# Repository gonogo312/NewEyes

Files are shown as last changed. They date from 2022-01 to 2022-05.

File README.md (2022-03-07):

# NewEyes - Умни очила за незрящи хора

# Автор

Иван Цветков - разработил проекта <br />
&emsp;• Username: gonogo, E-mail: i.tsvetkovbg@gmail.com

# Примери

## Screenshots

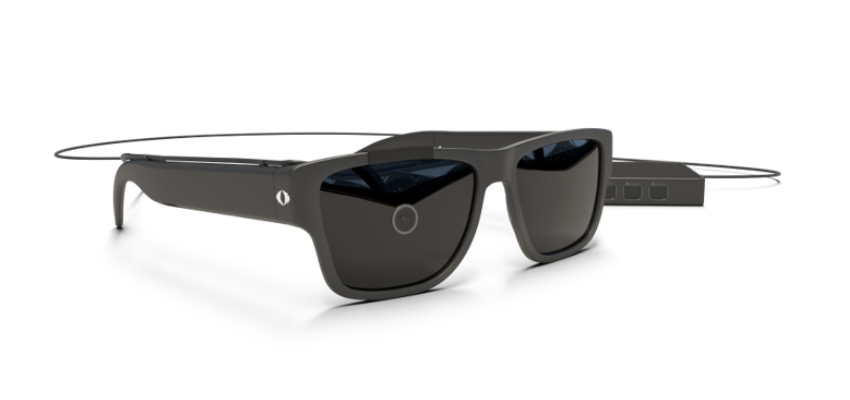
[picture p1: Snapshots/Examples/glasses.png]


<p float="left">
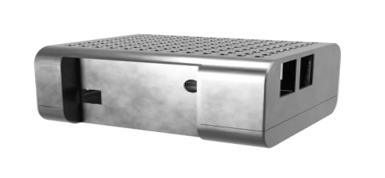
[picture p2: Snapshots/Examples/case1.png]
  
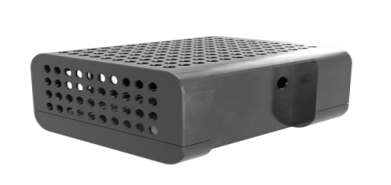
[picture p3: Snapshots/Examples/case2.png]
   
</p>

## Готов продукт

<p float="left">
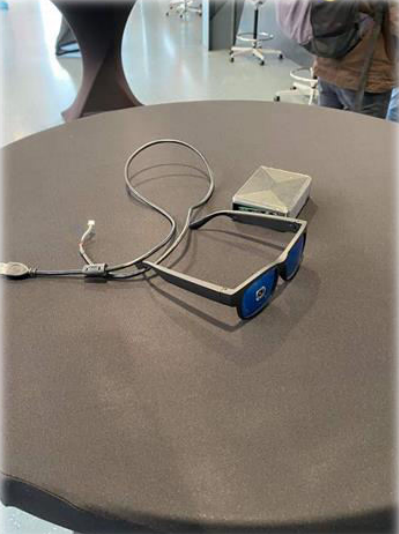
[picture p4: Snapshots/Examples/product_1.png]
  
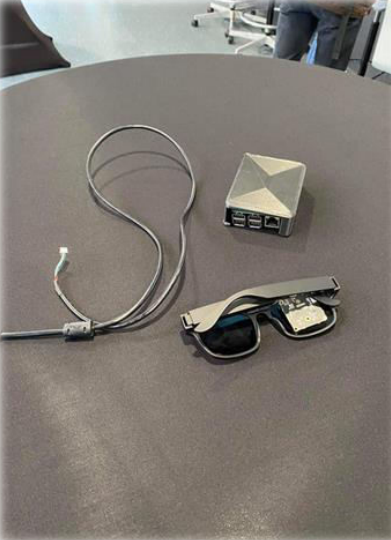
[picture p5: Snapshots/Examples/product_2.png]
   
</p>

## Четене на текст от Български и Английски език <br/>
(Допълнение: Ориентацията на снимките не е от значение, софтуера 
засича неправилната ориентация и изправя или обръща снимката)

<br/><br/>

## Четене на печатен текст  
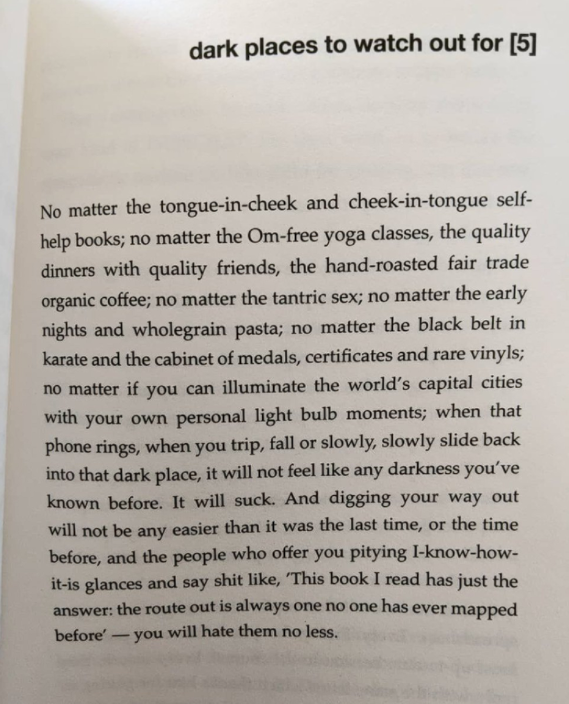
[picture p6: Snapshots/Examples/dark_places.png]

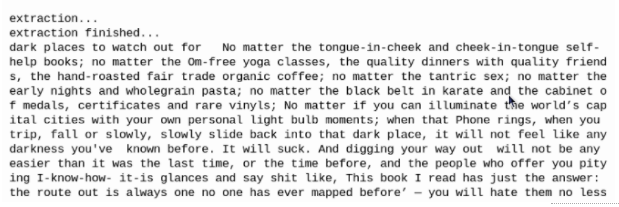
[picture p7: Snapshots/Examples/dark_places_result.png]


<br/><br/>

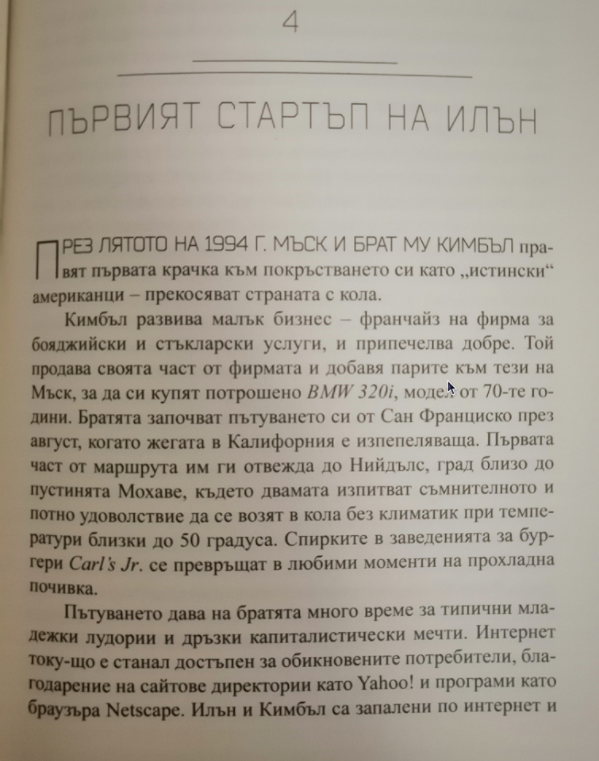
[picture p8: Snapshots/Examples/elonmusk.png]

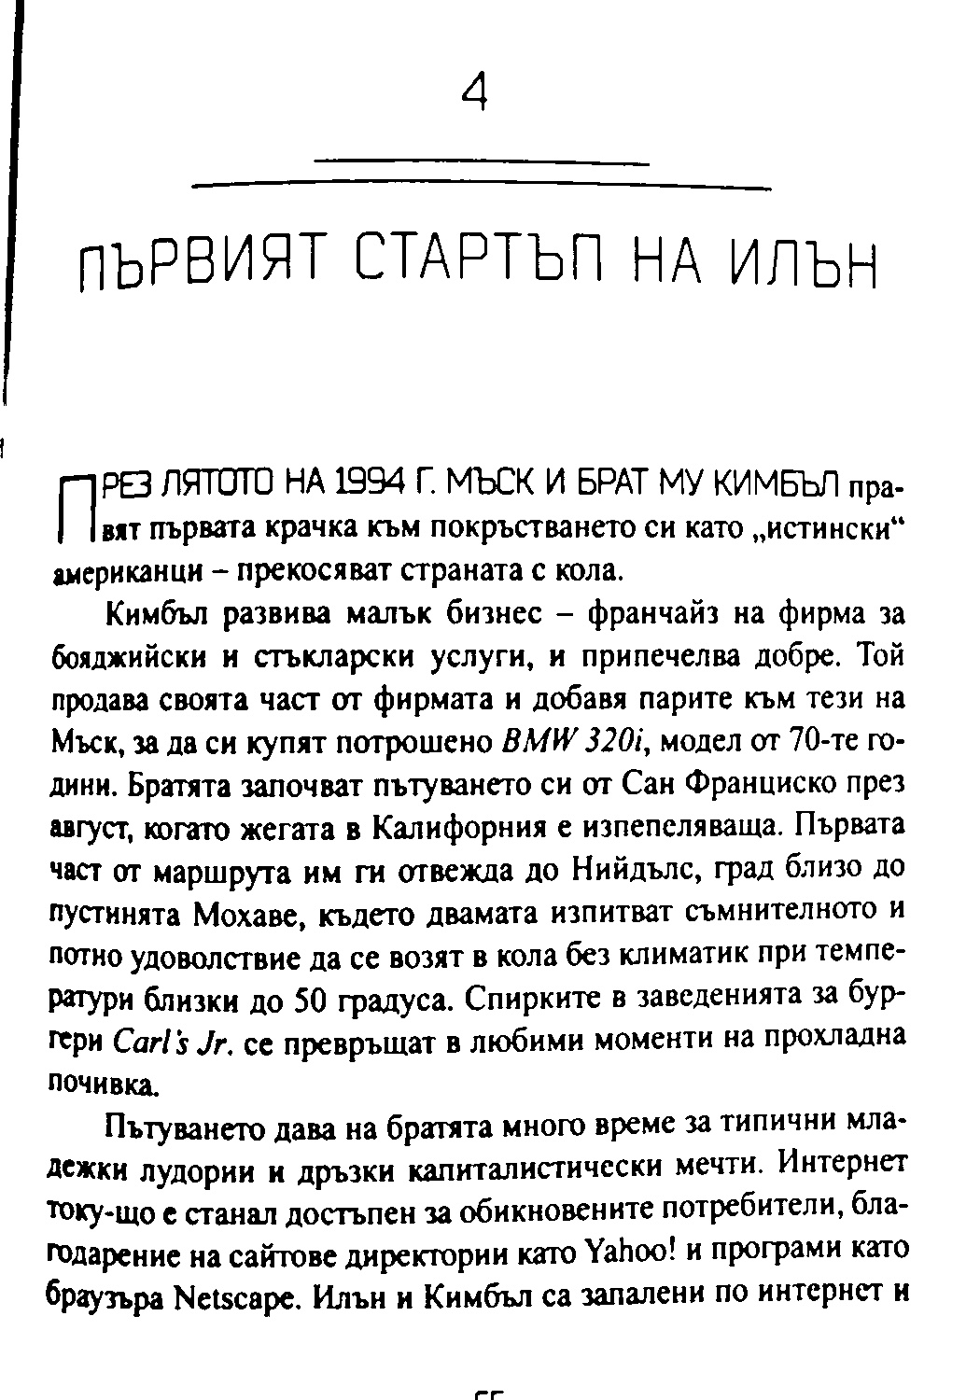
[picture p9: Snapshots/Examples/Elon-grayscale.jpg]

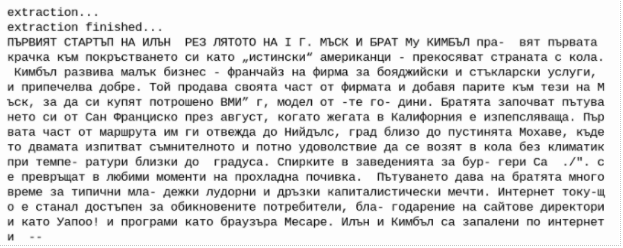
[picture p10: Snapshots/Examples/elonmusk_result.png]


<br/><br/>

## Пример за справяне с неправилната ориентация на текста

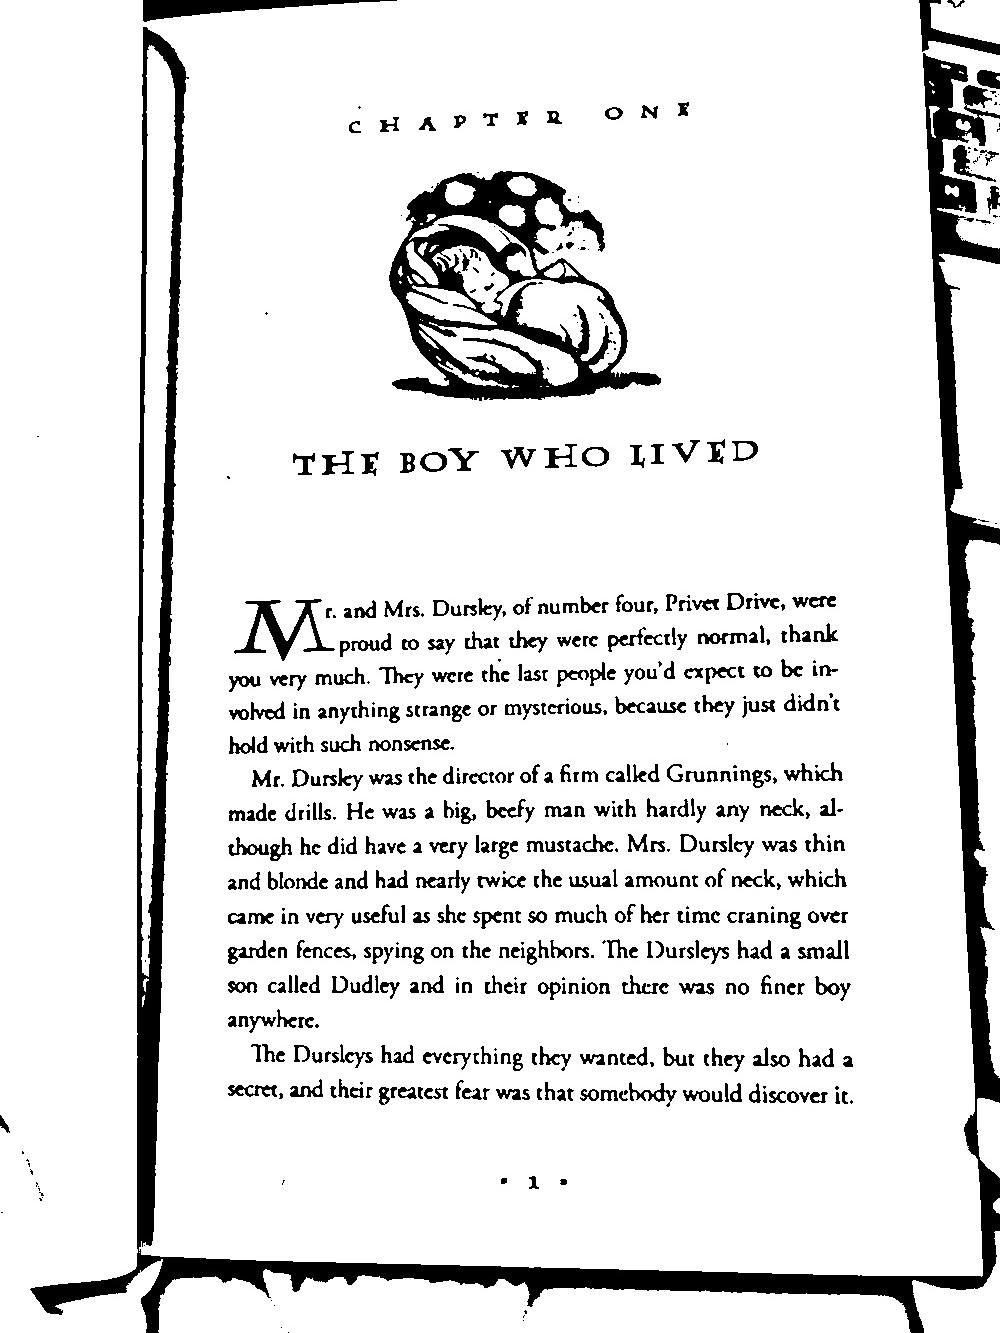
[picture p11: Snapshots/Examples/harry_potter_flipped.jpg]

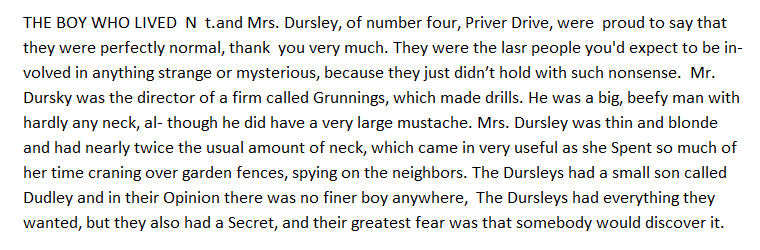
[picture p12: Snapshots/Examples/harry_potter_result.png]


<br/><br/>

## Четене на текст в необичайна среда
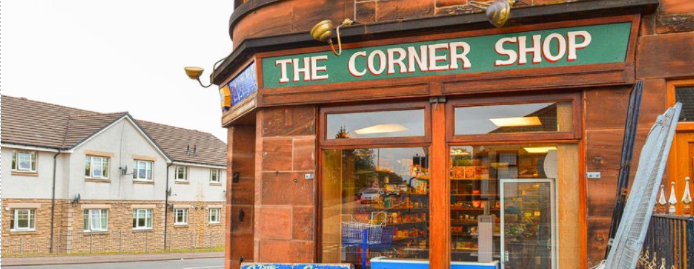
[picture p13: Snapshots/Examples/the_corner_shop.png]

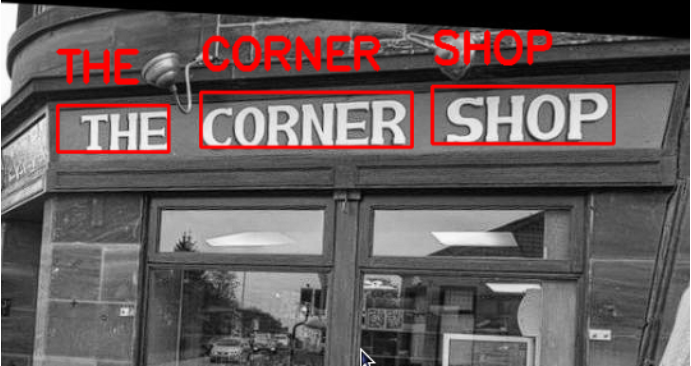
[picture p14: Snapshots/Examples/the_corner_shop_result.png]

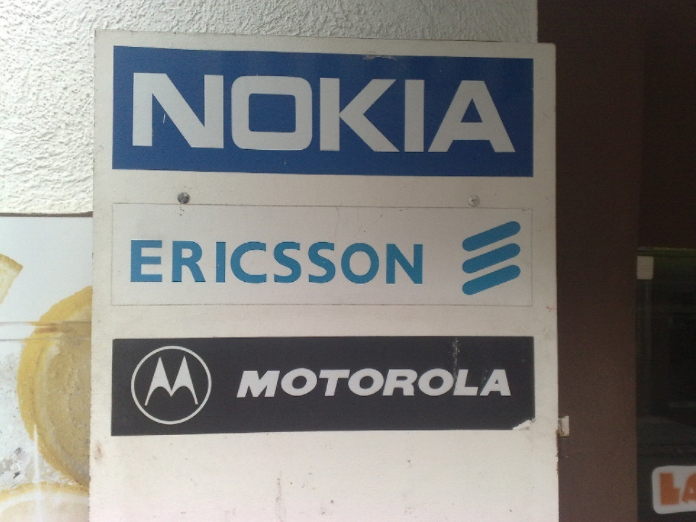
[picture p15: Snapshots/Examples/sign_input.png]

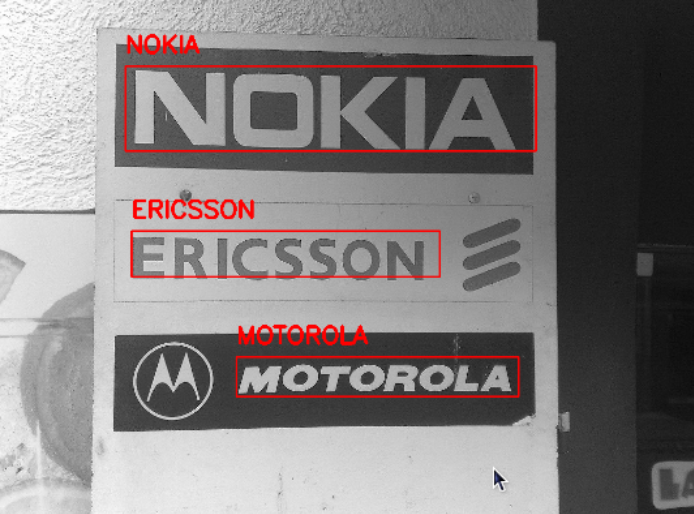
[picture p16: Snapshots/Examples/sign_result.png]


<br/><br/>

## Сканиране на касови бележки
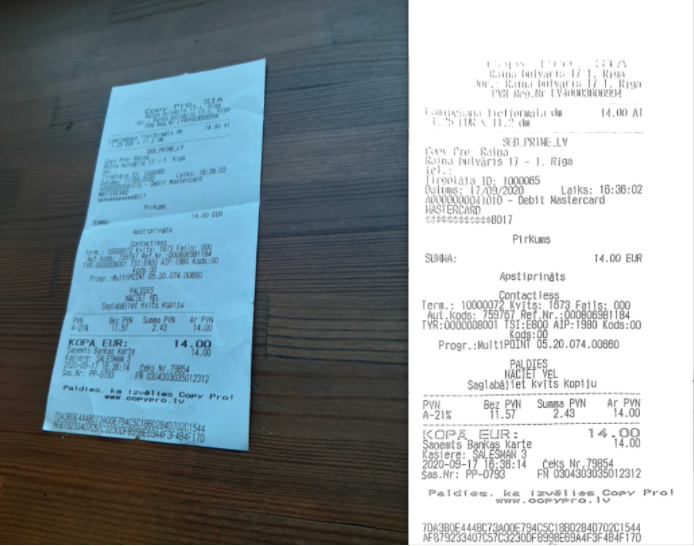
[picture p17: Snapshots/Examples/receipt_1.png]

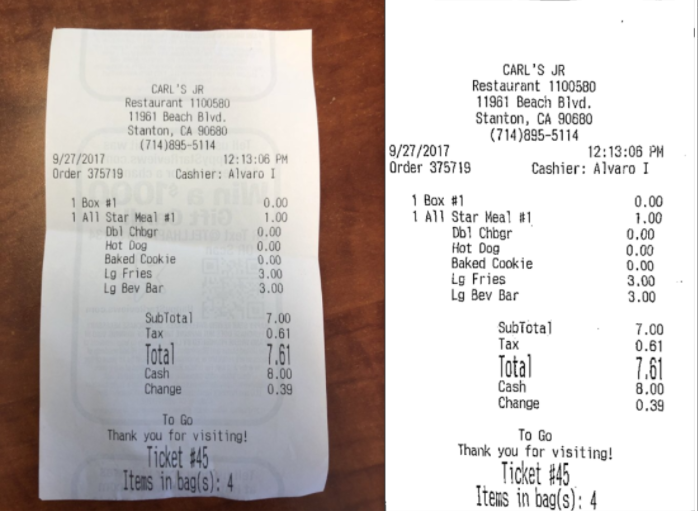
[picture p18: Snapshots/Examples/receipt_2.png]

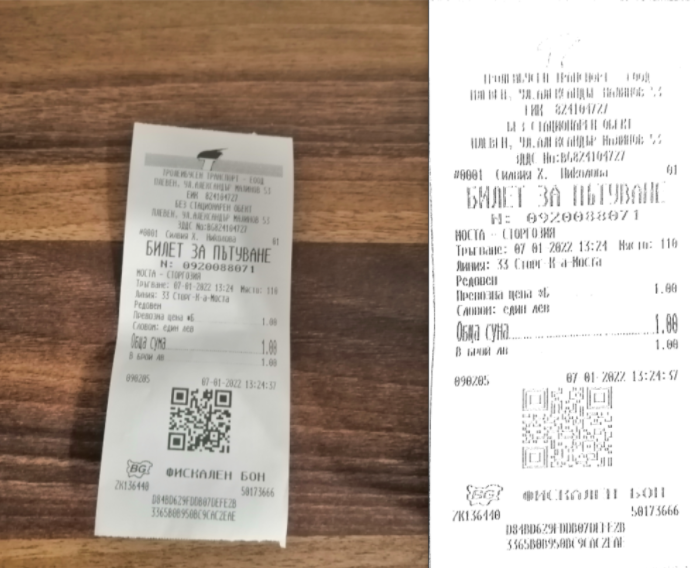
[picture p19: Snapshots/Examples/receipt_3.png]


<br/><br/><br/><br/><br/><br/>

## Разпознаване на обекти и тяхната позиция в пространството
Съответно, след цялостната обработка, разпознаването на обектите и превода на български език,
през говорителите на устройството или през свързаните към устройството слушалки, 
съответното съобщение се изговаря през говорителите или през слушалките в ухото на незрящия човек.

<br/>

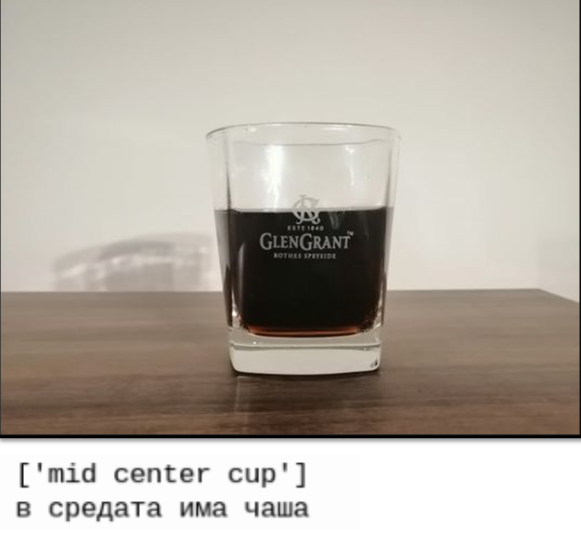
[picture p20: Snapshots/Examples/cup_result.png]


<br/>

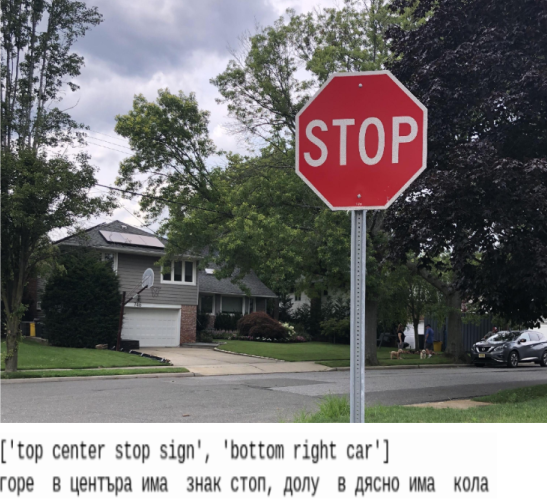
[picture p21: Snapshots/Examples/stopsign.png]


<br/><br/><br/><br/><br/><br/>

## Интерактивна помощ от друг човек чрез камерата на очилата 

Опцията представлява видеочат, чрез който незрящият бива  
навигиран от друг човек (познат/приятел/роднина), като връзката
се осъществява посредством платформата за видео чат Duo 

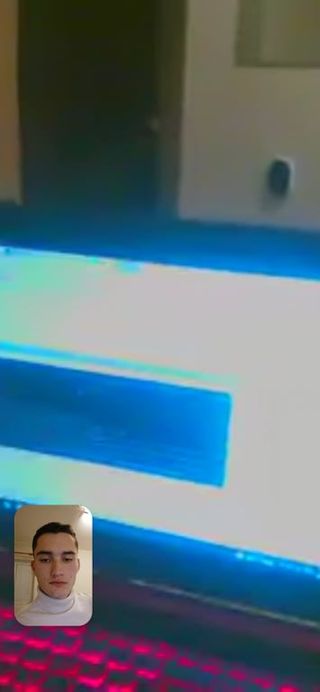
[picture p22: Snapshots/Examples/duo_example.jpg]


<br/><br/><br/><br/><br/><br/>

## Разпознаване на главен цвят от снимка
https://user-images.githubusercontent.com/97058791/152701536-6b37c342-0eb0-4af8-9801-c10c8d0b1d24.mp4

<br/><br/><br/><br/><br/><br/>

## Разпознаване на баркод и QR код
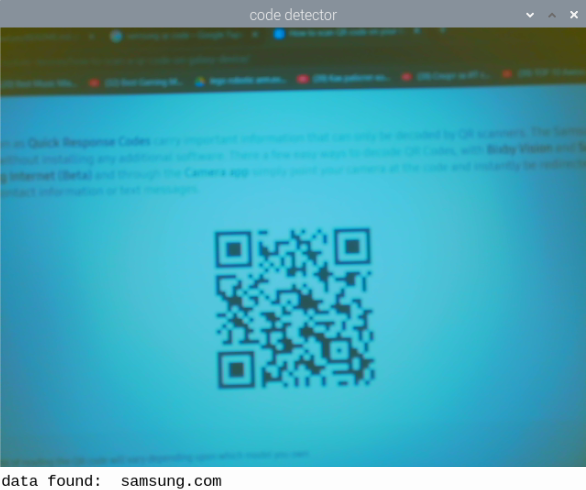
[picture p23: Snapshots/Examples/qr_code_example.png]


<br/><br/><br/><br/><br/><br/>

## Отличия
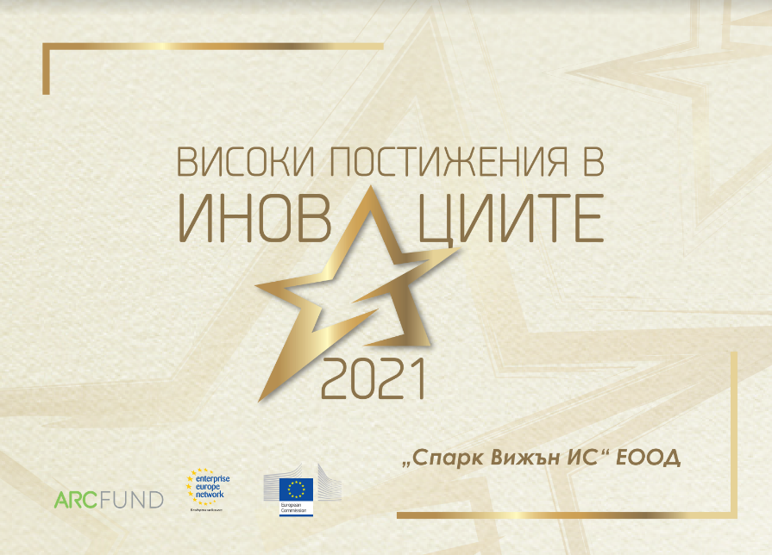
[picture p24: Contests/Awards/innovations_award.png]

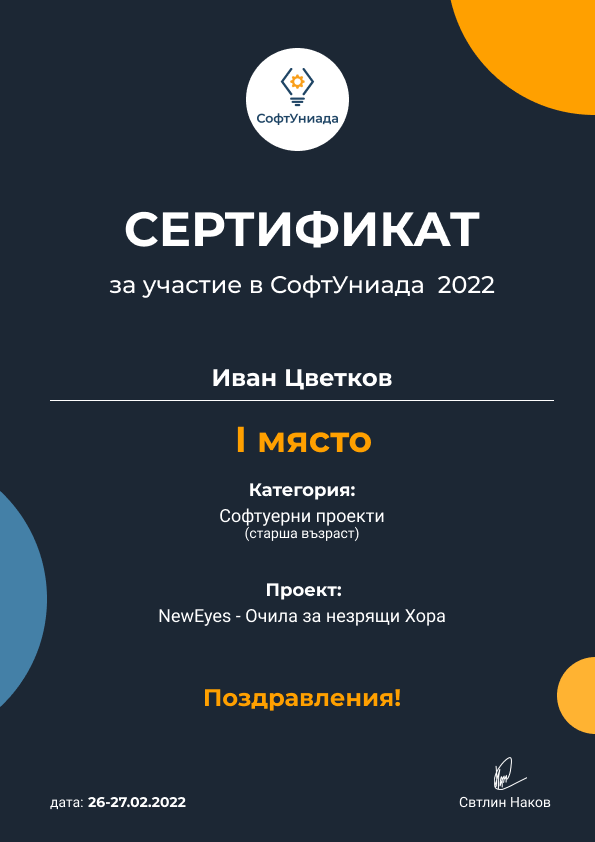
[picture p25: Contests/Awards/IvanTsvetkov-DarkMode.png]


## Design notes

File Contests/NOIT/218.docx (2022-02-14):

NewEyes

Проект №218 Съвременни системи за визуална информация

1. Тема: NewEyes – Очила за незрящи Хора
2. Автор:

Иван Мирославов Цветков

ЕГН: 0346233967

Адрес: Климент Охридски №12, гр. Долни Дъбник

Тел: 0899348344

Имейл: i.tsvetkovbg@gmail.com

МГ “Гео Милев” Плевен, 12 клас

3. Ръководител:

Илко Симеонов

Тел: 088 518 1556

Имейл: ilko.simeonov2000@gmail.com

Позиция: Програмист

Проект № 218, Съвременни системи за визуална информация

4. Резюме

4.1. Цели:

Целта на проекта е да подобри живота на незрящите / хората с тежко увредено зрение, като бъде неизменен помощник в тяхното ежедневие. В зависимост от това от което се нуждае незрящия в дадена ситуация, са предвидени различни по вид и функция функционалности (модове). Всяка функционалност изпълнява строго дефинирана функция, като това помага за лесната използваемост на устройството.

Наличните функционалности, които ще се поддържат от устройството са:

Избираеми функции:

- Четене на книжен/печатен текст
- Четене на текст в необичайна среда
- Единично разпознаване на обекти
- Разпознаване на обекти в реално време
- Позвъняване на познат при нужда от помощ
- Разпознаване на QR & Barcode кодове
- Сканиране на касови бележки
- Разпознаване на валута / банкноти
- Разпознаване на главен цвят в снимка
- Разпознаване на лица и емоции

Автоматични функции работещи винаги след стартирането на устройството:

- Разпознаване на жестове с ръце
- Умен гласов асистент

Програмният код е лицензиран под GNU General Public License v3.0

За разработката на проекта се използва Github, което представлява децентрализирана система за контрол на версиите на файлове. Програмният код и примери от главните функционалности на проекта са достъпни на следния адрес:

https://github.com/gonogo312/NewEyes

Проект № 218, Съвременни системи за визуална информация

4.2. Основни етапи в реализацията на проекта:

- Създаване на идеята
- Избиране на подходящи технологии
- Обмисляне на архитектурата и взаимодействието между различните модули
- Детайлно проучване нуждите на клиента
- План за реализация на проекта
- Разработка на устройството (хардуер/софтуер)
- Тестване на главните функционалности чрез помощта на незрящи доброволци
- Обработка на допълнителни клиентски изисквания / предложения
- Изкарване в продъкшън среда (готов за използване продукт)
- Бъдещи планове

4.3. Ниво на сложност на проекта:

В проекта са използвани множество модерни технологии и различни модули хардуер. Използваните технологии и библиотеки са проучени и тествани в реална среда, така че да изпълняват различните по вид функционалности на устройството по най-оптималният начин. Поради гореспоменатите причини определям „NewEyes“ като проект от високо ниво на сложност.

4.4. Логическо и функционално описание на решението:

4.4.1. Генерална архитектура

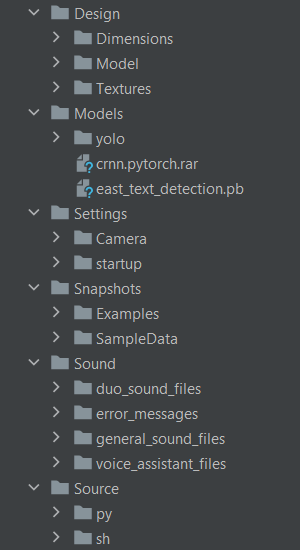
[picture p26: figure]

Проект № 218, Съвременни системи за визуална информация

- Design
  - Model

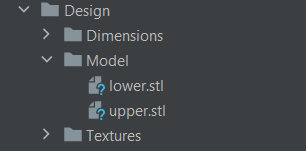
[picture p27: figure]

Upper.stl и съответно Lower.stl представляват двете части на модела от които е изградена кутията на устройството.

  - Dimensions

Съдържа схемите по които е изграден модела на кутията, съответно размерите на всеки елемент от хардуера в нея – едноплатков компютър Raspberry Pi 4, литиева батерия PiSugar2 Pro, SIM карта и други.

Проект № 218, Съвременни системи за визуална информация

  - Textures

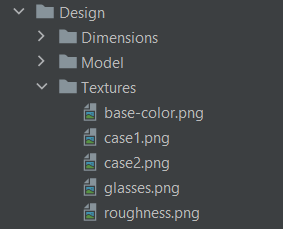
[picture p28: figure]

Съдържа отделните части на модела като изображение, цялостният модел и цветова гама на модела.

- Models

Yolo, CRNN.PythonTorch и east_text_detection моделите дават способността на устройството да разпознава текст и обекти по най-оптималният начин в съотношение с изчислителната мощност на хардуерните компоненти.

  - Yolo

Съвкупност от различни модели, използвани за разпознаване на обекти.

  - CRNN.PythonTorch

Модел и код за трениране на модела. Прилага се при разпознаването на текст в необичайна среда (функционалност №2) – четене на текст от табели, тролейбуси, коли и други идентични източници.

  - East_text_detection.pb

Подобен модел, използван при четенето на текст.

Проект № 218, Съвременни системи за визуална информация

- Source
- Python

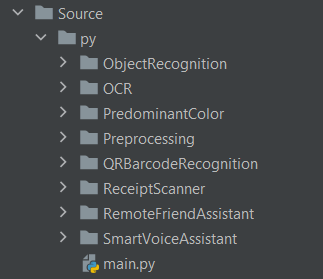
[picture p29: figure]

    - OCR

NewEyes.Source.python.OCR.book_ocr дава функционалността за четене на печатен текст.

NewEyes.Source.python.OCR.crnn_ocr предоставя функционалността за четене на текст в необичайна среда.

    - ObjectRecognition

NewEyes.Source.python.ObjectRecognition.yolo съдържа класовете и методите за разпознаването на обекти, тяхната позиция в пространството и разстоянието до всеки обект.

NewEyes.Source.python.ObjectRecognition.start_obj_recog

предоставя функционалността за разпознаване на обекти от снимка.

NewEyes.Source.python.ObjectRecognition.realtime_yolo_obj_recog предоставя

функционалността за разпознаване на обекти в реално време.

    - PredominantColor

NewEyes.Source.python.PredominantColor.predominant_clr дава функционалността за разпознаване на главен цвят от снимка.

Проект № 218, Съвременни системи за визуална информация

    - Preprocessing

NewEyes.Source.python.Preprocessing.image_processing пази методите използвани за обработката на снимките.

    - QRBarcodeRecognition

NewEyes.Source.python.QRBarcodeRecognition.qr_barcode функционалност за разпознаване на QR & Barcode кодове в реално време.

    - ReceiptScanner

NewEyes.Source.python.ReceiptScanner.receipt_scanner съдържа функционалността за сканирането и четенето на касови бележки.

    - RemoteFriendAssistant

NewEyes.Source.python.RemoteFriendAssistant.duo_google пази функционалността за позвъняване на друг човек чрез мобилният му номер и фийд от камерата чрез платформата Duo.

    - SmartVoiceAssistant

NewEyes.Source.python.SmartVoiceAssistant.voice_recog дава функционалността за Speech-to-Text, което се използва при функционалността гласов асистент.

    - HandGestureRecognition

NewEyes.Source.python.HandGestureRecognition дава функционалността за разпознаване на жестове с ръце.

    - Main.py

Съдържа основният код, чрез който потребителят навигира през списъка с функционалностите, изпълнява избрана функционалност. При стартиране се създават нишки (Threads) за функционалностите SmartVoiceAssistant и HandGestureRecognition.

Проект № 218, Съвременни системи за визуална информация

  - Bashsc

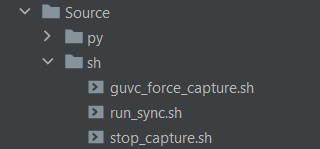
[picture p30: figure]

    - Guvc_force_capture.sh прави снимка чрез камерата на очилата чрез програмата guvcview (софтуер използван за обработката на UVC потоци).
    - Stop_capture.sh изключва guvcview след като се направи и запази снимката.
    - Run_sync спрямо въведена часова зона, синхронизира часовника на устройството чрез NTP (Network Time Protocol).
- Settings
- Camera
  - NewEyes.Settings.Camera.default.gpfl съдържа настройки за конфигуриране на параметри като Focus, Brightness, Contrast, Saturation и други, използвани при правенето на снимка чрез софтуера guvcview.

Проект № 218, Съвременни системи за визуална информация

- Startup/autostart
- NewEyes.Settings.startup.autostart.autorunfile.desktop съдържа инструкции чрез които при включване на устройството се изпълнява основният код, main.py.
- Snapshots

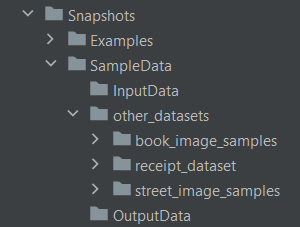
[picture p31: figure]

- Examples

Съдържа примери от главните функционалности и техните резултати.

- SampleData/other_datasets съдържа примери използвани при тестването на функционалностите и dataset използван при тестването на функционалността ReceiptScanner.

Проект № 218, Съвременни системи за визуална информация

- Sound

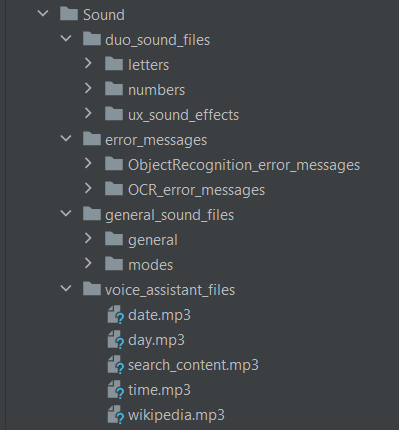
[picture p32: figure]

Съдържа аудио файловете във формат *.mp3 и *.wav използвани при различните функционалности, разделят се в 4 основни категории:

- General_sound_files
- Duo_sound_files
- Error_messages
- Voice_assistant_files

4.4.2. Използвани библиотеки:

- GoogleSpeech – Speech класа позволява създаването на *.mp3 файлове с даден текст.
- GpioZero – Button класа позволява достъпа до бутоните.

Проект № 218, Съвременни системи за визуална информация

- OS & MPG312 – OS библиотеката позволява извикването на MPG312 music player, който прави възможно извикването и изпълняването на аудио файлове.
- Imutils – Предоставя базови функции за обработка на снимки, като някои от тях са non_max_suppression, label_contour, four_point_transform, put_text и други.
- Pytesseract – Енджин, използван при разпознаването на текст от снимка, предоставящ различните модове/опции още наречени Page Segmentation Modes и OCR Engine Mode или PSM и OEM. Някои от използваните модове в проекта са:

PSM

1. Automatic page segmentation with OSD.
2. Fully automatic page segmentation (No OSD)

OEM

1. Neural nets LSTM engine only.
2. Legacy + LSTM engines.
3. Default
- Subprocess – Библиотека предоставяща функционалността за създаване на нови процеси използвани за изпълняването на функциите на устройството изпълняващи се в реално време.
- Threading – Класът Thread дава възможност за създаването на нови нишки използвани за изпълнението на функционалности като SmartVoiceAssistant, HandGestureRecognition.
- Pyzbar – Декодира засеченият QR или Баркод.
- TextBlob – TextBlob API позволява поправка на грешно прочетен текст чрез NLP (Natural Language Processing), който дава възможността детайлен анализ на върнатият текст. Някои от възможностите на библиотеката са: Sentiment analysis, Classification, Parsing, Spelling correction и други.

Проект № 218, Съвременни системи за визуална информация

- OpenCV – Предоставя множество фундаментални функции използвани при обработката на снимки и заснемане в реално време.
- MySql.Connector – Предоставя достъп до локалната MySQL база данни, което позволява изпълняването на заявки за четене и промяна на данни.
- SpeechRecognition – Дава възможността за Speech-to-Text.
- Други библиотеки – Numpy, argparse, random, time, datetime, sys, io, signal, pyttsx3, pygame, skigame, pynput, webbrowser, pyautogui, wikipedia, re.

Структура на MySQL базата данни:

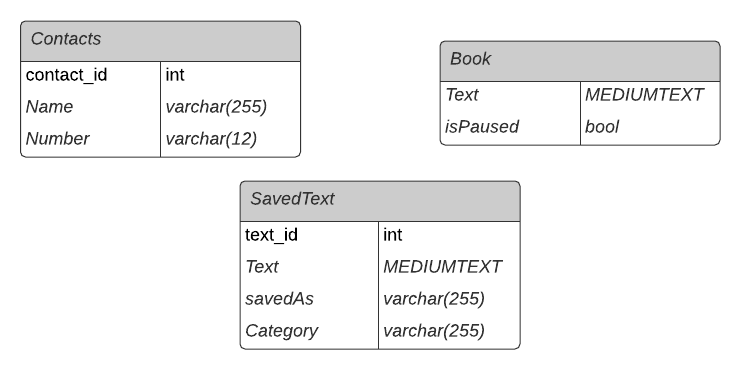
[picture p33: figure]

Проект № 218, Съвременни системи за визуална информация

4.4.3. Хардуерна архитектура и компоненти

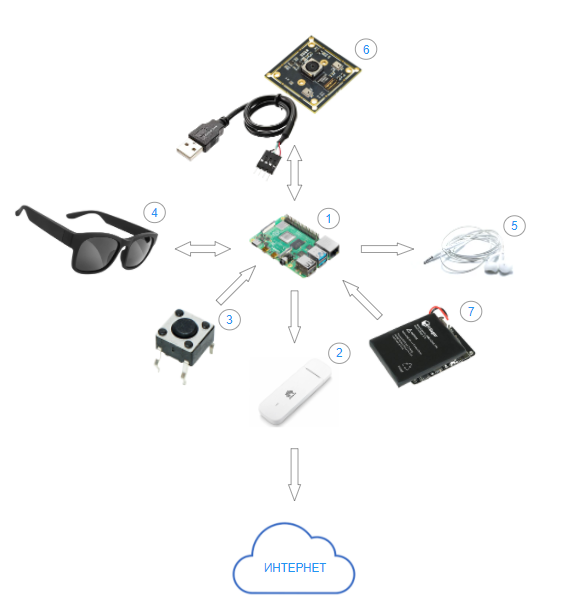
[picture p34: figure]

1. Компютър Raspberry Pi 4 Model B

2. Huawei 4G Dongle

3. 3x Бутона

4. Bluetooth очила с вградени говорители

5. Слушалки (по избор)

6. Arducam 4K 16MP камера

7. Pisugar2 | Литиева Батерия | 5000mAh

Проект № 218, Съвременни системи за визуална информация

4.4.4. Дизайн на системата


Проект № 218, Съвременни системи за визуална информация

4.4.5. Външен вид на готовият продукт

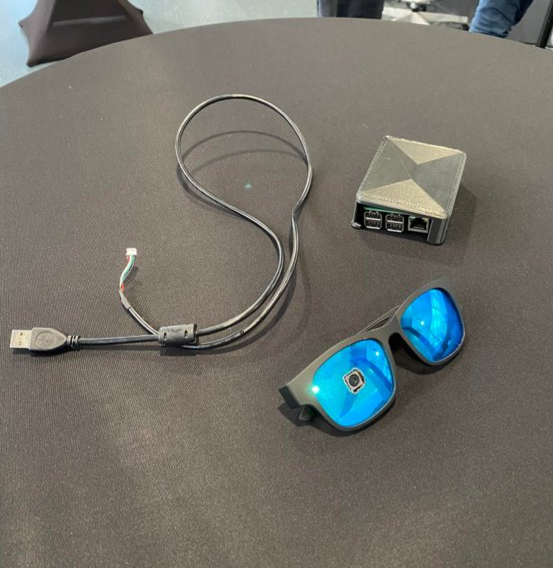
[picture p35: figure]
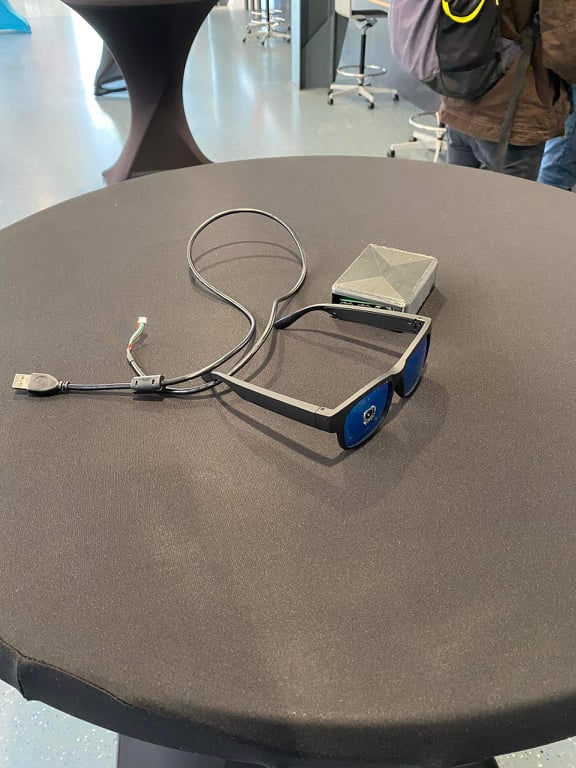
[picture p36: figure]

4.5. Реализация:

4.5.1. Избор на технологии

За разработката на проекта са проучени в детайли и избрани набор от модерни технологии и инструменти.

Технологиите включват програмен език Python, MySQL база данни, Pytesseract енджин за извличане на текст от снимка, OpenCV обработка на снимки и други.

Проект № 218, Съвременни системи за визуална информация

4.5.2. Описание на софтуерните решения

При разработката на различните функционалности са използвани различен набор от стъпки и инструменти при обработката за постигане на оптимални резултати. Използвани алгоритми и техники при разработването на модовете са следните:

1. Алгоритъм при обработката на снимки съдържащи печатен текст
- Grayscale

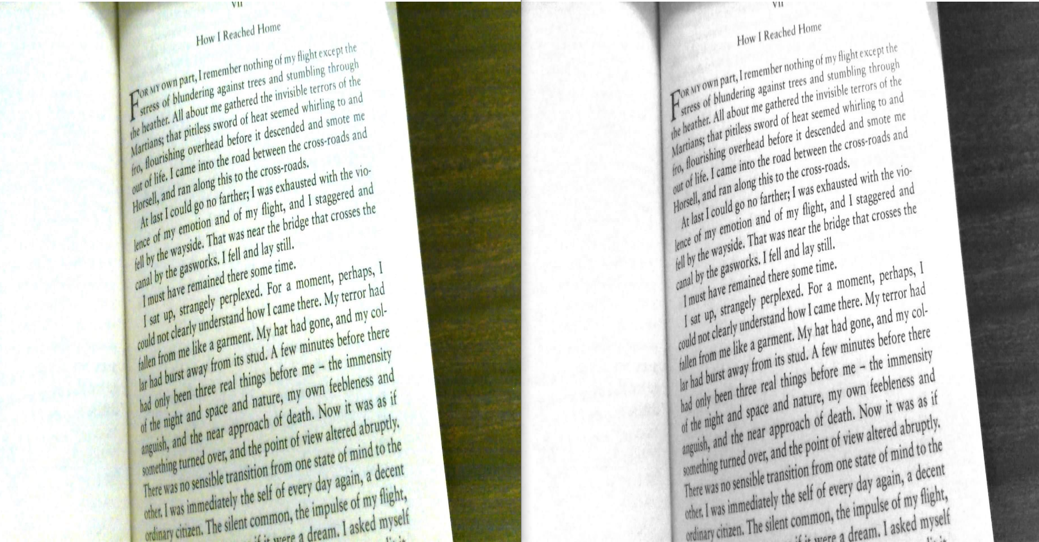
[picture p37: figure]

Проект № 218, Съвременни системи за визуална информация

- Deskew - Изправяне на снимката спрямо ориентацията на текста.

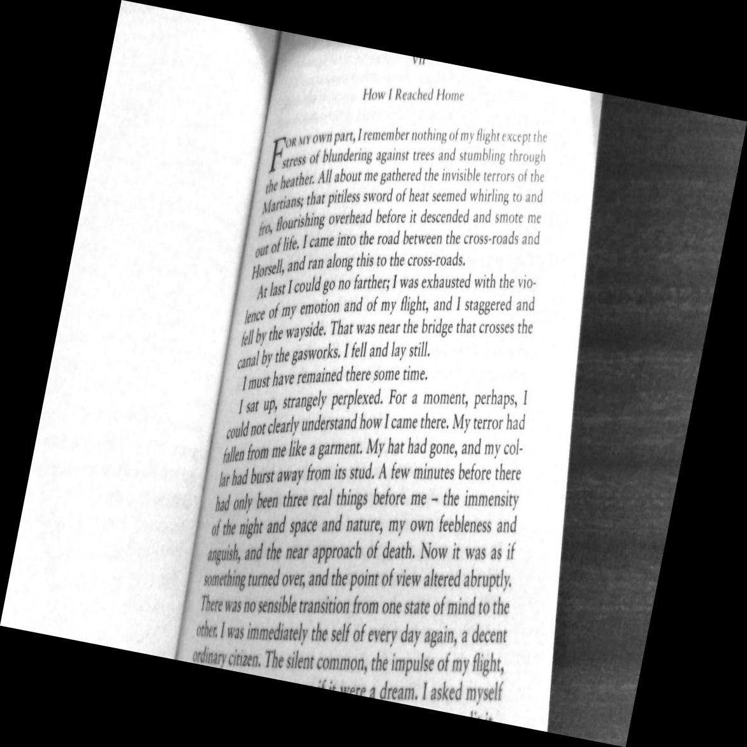
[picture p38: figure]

- OSD - Проверка на ориентацията, идентифициране на езика, при допусната грешка в ориентацията на текста, снимката се преработва отново.
- Dilation - Морфологична операция, увеличаваща белият регион от снимката.
- Noise Reduction - Намаляване на шума от снимката, чрез използването на median blur.
- Adaptive Thresholding - Поради способността да задава автоматично thresholding стойности за всеки пиксел се намалява загубата на информация от снимката до минимум.

Проект № 218, Съвременни системи за визуална информация

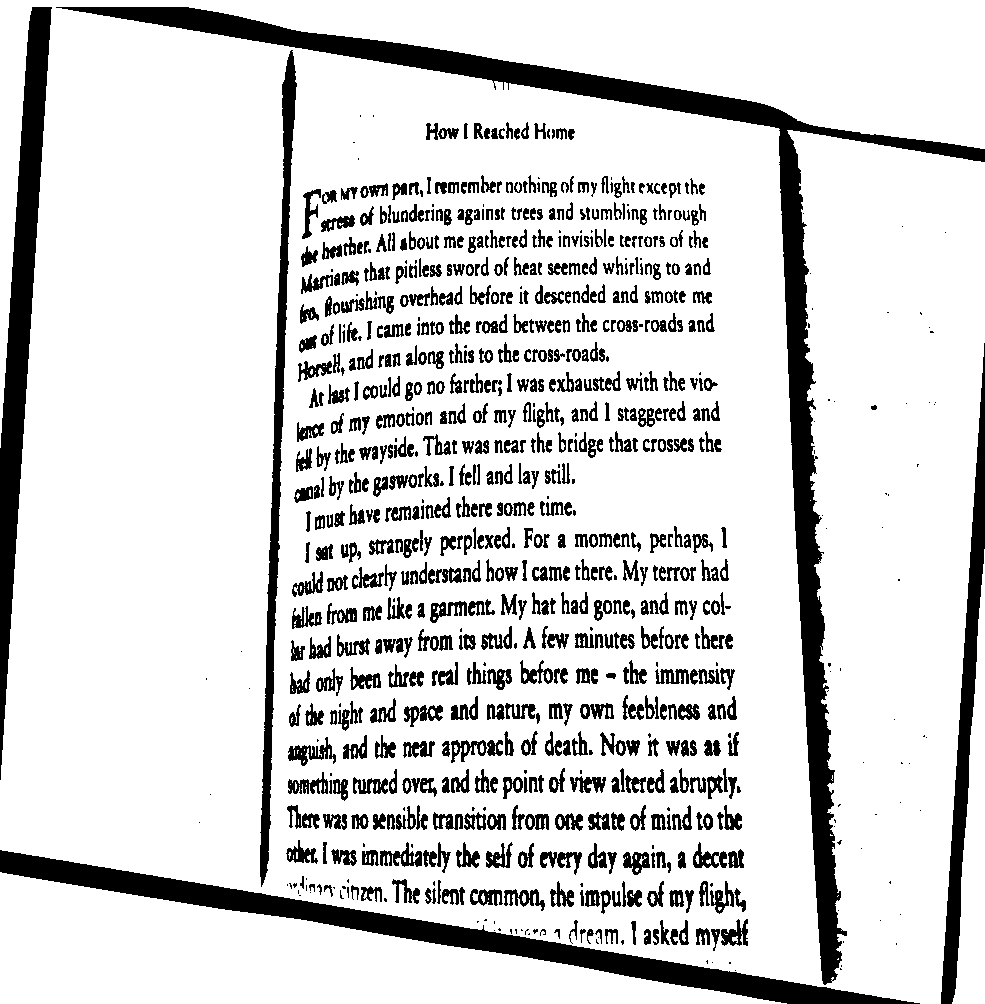
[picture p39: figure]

- Извличане на текста с Pytesseract

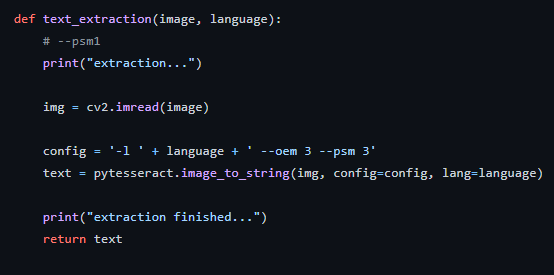
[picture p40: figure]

Проект № 218, Съвременни системи за визуална информация

Резултат:

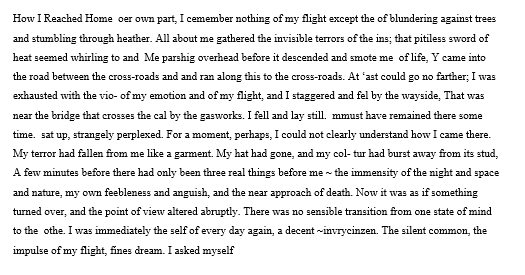
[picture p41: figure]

2. Алгоритъм при обработката на снимки съдържащи текст в необичайна среда

За обработката на снимки в необичайна среда се използва невронна мрежа тип FCN – Fully Convolutional Network.

- При обработката, на снимката се засичат Bounding Boxes на отдените парчета текст чрез FCN моделът на невронната мрежа.
- След засичането на всички налични Bounding Boxes, Non-Maximum Suppression техниката премахва онези Bounding Boxes, които са с коефициент на точност – confidence, по-нисък от зададеният. В нашият случай, коефициентът на точност е 0.6, при което се елиминират повечето засечени Bounding Boxes на обектите.

Проект № 218, Съвременни системи за визуална информация

- След филтрацията на кутиите чрез Non-Maximum Suppression, чрез IoU – Intersection Over Union техниката, намираме сечението на останалите Bounding Boxes.
- Извличаме текста от всяка резултантна кутия чрез Pytesseract.

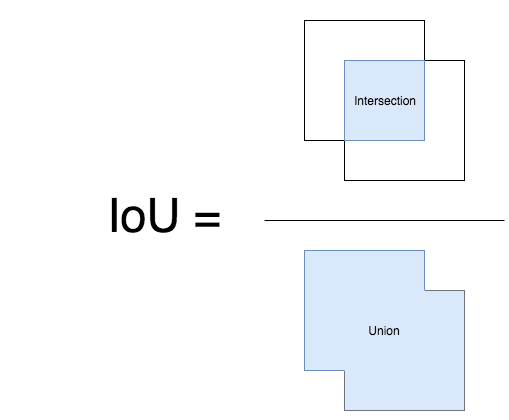
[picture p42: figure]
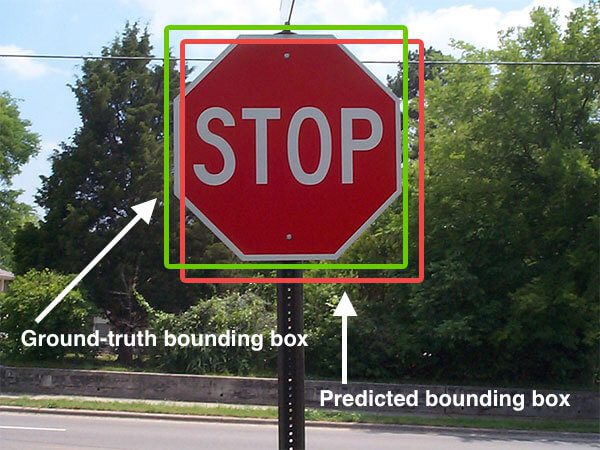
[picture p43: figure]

Проект № 218, Съвременни системи за визуална информация

3. Алгоритъм при обработката на снимки съдържащи обекти

При обработката се използва система за засичане на обекти наречена YOLO – You Look Only Once. Използваната невронна мрежа от YOLO е от тип CNN – Convolutional Neural Network. Предимството на YOLO е в бързината и точността, като за разлика от други невронни мрежи като R-CNN – Region-based Convolutional Neural Network и FAST R-CNN, които се нуждаят от множество повторения на стъпките, YOLO извършва всички стъпки само веднъж. Стъпките през които YOLO минава за разпознаване на обектите от дадена снимка са следните:

Термини:

Classification – Спрямо вида на обекта се задава клас, който отговаря на характеристиките на дадения клас.

Localization – Намиране на местоположението на обект и създаване на Bounding Box около него.

- Локализация на обектите и задаване на Bounding Boxes около обектите, коефициент на точност и класификация за всеки обект.
- Използване на техниката Non-Maximum Suppression.
- Използване на техниката Intersection over Union.
- Извличане на данните за обектите от всяка резултантна кутия.
4. Алгоритъм при сканирането на касови бележки
- Edge Detection - Намиране на върховете на касовият бон.

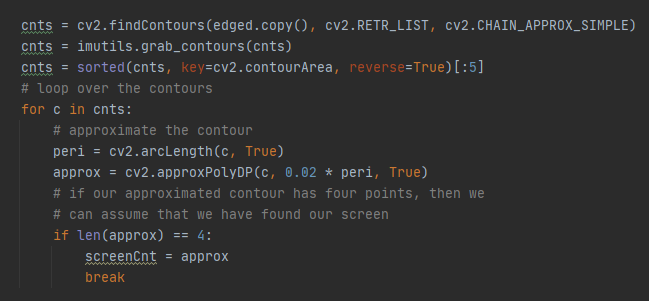
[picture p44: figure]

Проект № 218, Съвременни системи за визуална информация

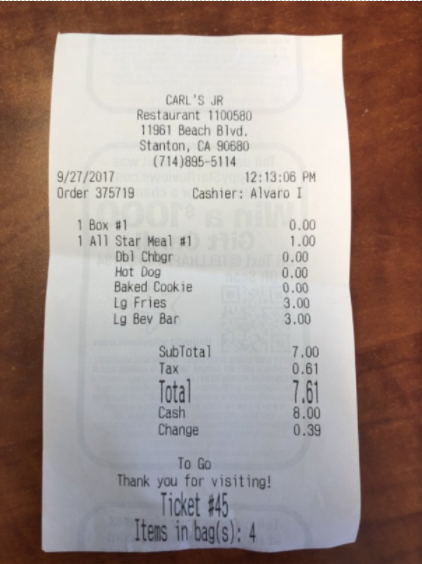
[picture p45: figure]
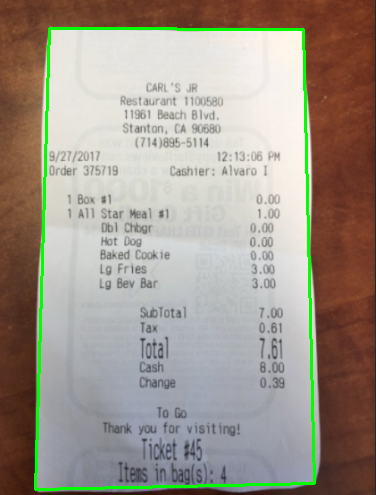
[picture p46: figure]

- Преобразуване на засечения регион в 2D картина, чрез което енджинът за извличане на текст се справя оптимално при извличането на текст от касови бележки.

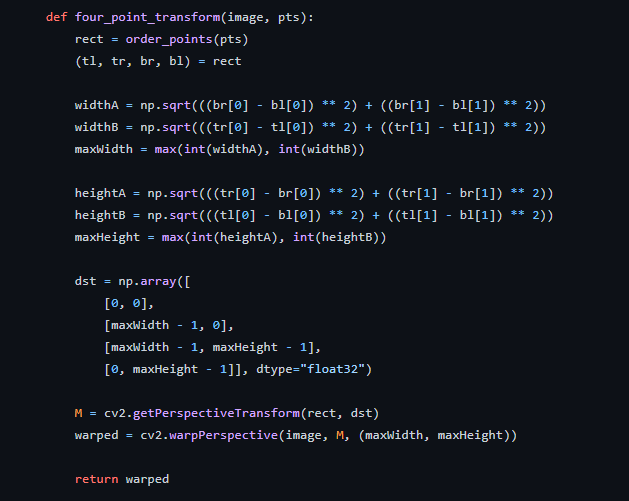
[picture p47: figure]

Проект № 218, Съвременни системи за визуална информация

Резултат от обработката:

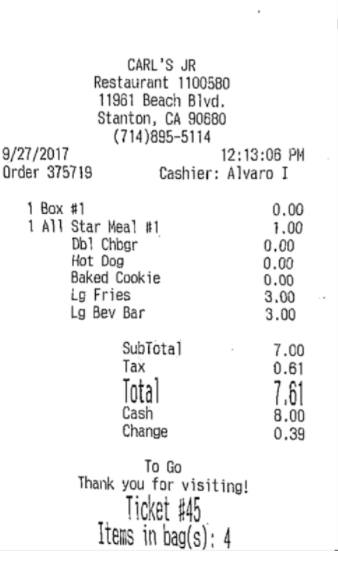
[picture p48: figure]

За обработката на снимки при разпознаването на валута / банкноти и тяхната стойност се обработват данните по идентичен начин както при сканирането на касови бележки.

Проект № 218, Съвременни системи за визуална информация

4.6. Описание на приложението:

Менюто на устройството е проектирано по лесен за навигиране и използване начин от страна на потребителя. Преди използване се поставят очилата, като устройството седи в джоба/ръката на незрящия човек. 3D структурата и тежестта на устройството го прави удобно при използване за дълъг период от време.

- Устройството се стартира чрез Switch от дясната страна на кутията.
- Избираеми опции и активация: При натискането на бутона за активиране на избрана функционалност, компютъра подава сигнал към камерата и прави снимка или съответно пуска Realtime Video Stream от който да вземе всеки фрейм по отделно. Като след обработката, от говорителите на очилата се изговаря съответното съобщение.
- Функции работещи в реално време: По всяко време след стартирането, независимо от избраната чрез бутоните опция, гласовият асистент изчаква команда за активация. При изричането на дефинираната команда, гласовият асистент позволява притока на входни данни. Пример за това са известните гласови асистенти като Siri, Alexa и други. Някои от функциите на гласовият асистент са активиране на функционалност, търсене в интернет, пускане на музика, спиране и пускане на звуков файл, запазване в базата данни прочетен текст от книга. Разпознаването на жестове с ръце позволява функции като спиране, пускане на звуков файл, намаляване на звука от говорителите и други.

Практически примери на някои от функционалностите (стар модел на очилата с работещи главни функционалности за четене на текст и разпознаване на обекти) и интервю с Инж. Павлин Ангелов, член на Управителният Съвет на Съюзът на Слепите Хора в България са достъпни на следния адрес:

https://sparkvision.tech

Проект № 218, Съвременни системи за визуална информация

4.7. Заключение:

NewEyes е устройство, което дава на незрящите хора онази самостоятелност и независимост, която не са имали преди. Проектът има за цел да подобри живота на незрящите хора, като бъде неизменен помощник в тяхното ежедневие. Уникалното на NewEyes е това, че е един от първите по рода си проект, които улесняват живота на незрящите хора и хората с тежко увредено зрение, като им помагат с ежедневни дейности. Основните проблеми на проекта бяха успешно разрешени. За в бъдеще се очаква разрастване, подобряване и добавяне на нови функционалности, като голяма част от тях идват от обратната връзка и контакта с незрящите хора от Съюза на Слепите Хора в България използващи устройството ежедневно.

Основните предимства на NewEyes са бързодействието и точността, затова ще се обърне внимание на следните характеристики на устройството:

- Хардуерна оптимизация
- Бързодействие при изпълнение
- Точност при изпълнение
- Подобряване на наличните функционалности
- Добавяне на нови функционалности
- Дистанционни софтуерни ъпдейти
- Други

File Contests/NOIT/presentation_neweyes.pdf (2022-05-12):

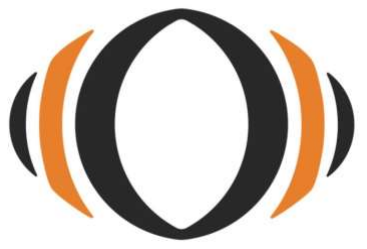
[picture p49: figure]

# NewEyes

## КАКВО ПРЕДСТАВЛЯВА ПРОЕКТЪТ?


NewEyes представляват очила, които подобряват живота на слепите хора и хората с тежко
увредено | зрение, | като | им
помагат с ежедневни дейности.

## ФУНКЦИОНАЛНОСТИ

✓ Четене на текст от различни източници на български и английски език
- Четене на печатен текст
- Четене на текст в необичайна среда

✓ Разпознаване на обекти
- Разпознаване на обекти от снимка
- Разпознаване на обекти в реално време

✓ Позвъняване на познат при нужда от помощ ✓ Разпознаване на баркод и QR код
✓ Сканиране и прочит на касови бележки
✓ Разпознаване на валута и стойност
✓ Разпознаване на цвят
✓ Разпознаване на жестове с ръце
✓ Гласов асистент


## КАК РАБОТИ?

## ПРИМЕРИ


## УСЪВЪРШЕНСТВАНЕ И БЪДЕЩИ ПОДОБРЕНИЯ


### - Хардуерна оптимизация

### - Софтуерна оптимизация

### - Бързодействие и точност при изпълнение

### - Подобряване на наличните функционалности

### - Добавяне на нови функционалности

### - Други


## ХАРДУЕРНА АРХИТЕКТУРА


1. Компютър Raspberry Pi 4 Model B
2. Huawei 4G Dongle
3. Бутони
4. Bluetooth очила с вградени говорители
5. Слушалки (по избор)
6. Arducam 4K 16MP камера
7. Pisugar2 | Литиева Батерия | 5000mAh

## ВЗАИМОДЕЙСТВИЕ


Взаимодействието между хардуера
и | софтуера | се | извършва | от
специален едноплатков компютър Raspberry Pi 4.


## С КАКВО Е УНИКАЛЕН ПРОЕКТЪТ?


- Висококачествен продукт;
- Бързодействие и точност;
- Голям брой поддържани функционалности;
- Най–ниска цена на световния пазар;
- Един от първите по рода си проект;
- Полезен за обществото и света;


# БЛАГОДАРЯ ЗА ВНИМАНИЕТО!

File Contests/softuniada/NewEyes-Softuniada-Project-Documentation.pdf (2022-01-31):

# NewEyes - Очила за незрящи Хора

“NewEyes” представлява устройство, изградено от кутия с няколко бутона, която е свързана към камера, закрепена за рамката на специални очила.

## Категория

Хардуер/Уеб Приложение

## Възрастова група

Над 16 години

## Описание

### 1. Какъв проблем решава?

Проектът има за цел да улесни/подобри живота на незрящите хора, като бъде неизменен помощник в тяхното ежедневие.

### 2. За кого е предназначен проектът?

Проектът е предназначен за незрящи / хора с тежко увредено зрение.

### 3. Защо е уникален проектът?

Уникалното на “NewEyes” е това, че е един от първите по рода си проект, който подобрява живота на слепите хора, като им дава онази самостоятелност и независимост, която не са имали до този момент.

### 4. Завършен ли е проектът или е само прототип?

Проектът е завършен, но основна цел е работата по него да продължи и за в бъдеще.

## Screenshots


### Как изглежда вече готовият продукт:


## Екип

- Иван Цветков - Разработчик на проекта
- SoftUni Username: gonogo, Tel. 0899 348 344, E-mail: i.tsvetkovbg@gmail.com

### Линк за / демо / видео / разговор със незрящ човек (

1. Линк към проекта и видеоклип: https://sparkvision.tech/

## Технологии

“NewEyes” съдържа съвкупност от технологии, използвани за

различните функционалности, сред които:

Програмен език - Python

Tesseract, OpenCV, YOLO, PyTorch, TensorFlow, SpeechRecognition, MySQL, Pandas и др.

### Хардуерна архитектура и физически компоненти:


Слушалките не са задължителни, тъй като очилата разполагат със собствени говорители. Също така, устройството има и батерия, прикачена към компютъра, която позволява работно време от 4-6 часа.

## Source Code

Линк към сорс кода за устройството: https://github.com/gonogo312/NewEyes

## Подробно описание

“NewEyes” представлява устройство, изградено от кутия с няколко бутона, която е свързана към камера, закрепена за рамката на специални очила. Целта на проекта е да помага на незрящите хора в ежедневни дейности и ориентация в необичайна среда, примери за това са:

1. Четене на текст от книги, табели, тролейбуси и други източници;

### 2. Разпознаване на обекти и тяхната позиция в пространството еднократно от

направена снимка;
3. Разпознаване на обекти и тяхната позиция в пространството в реално време;
4. Позвъняване на приятел, който да навигира незрящия човек през камерата;

5. Разпознаване на QR & Barcode кодове (Пример: Продукти в магазин);
6. Сканиране и прочитане на информация от касови бележки;
7. Разпознаване и броене на банкноти;
8. Разпознаване на цвета на даден обект;
9. Разпознаване на лица и емоции;

### 10. Разпознаване на жестове с ръце, чрез които могат да се активират и деактивират

дадени функционалности, намаляване на звука от говорителите и др.;

### 11. Интерактивни гласови команди

(Търсене на информация в интернет, пускане на музика, използване на всички гореспоменати функционалности чрез гласова команда и др.);

## Примери от някои от главните функционалности

https://github.com/gonogo312/NewEyes/blob/main/README.md

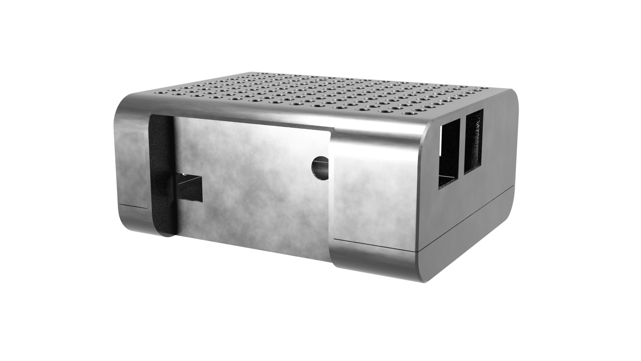
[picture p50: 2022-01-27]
Design/textures/case1.png

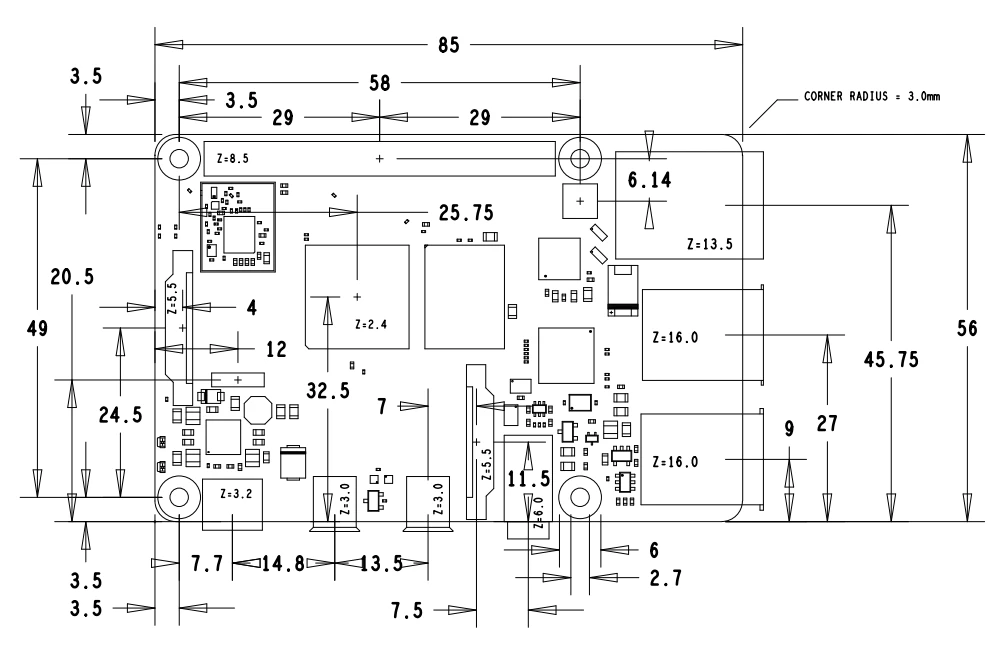
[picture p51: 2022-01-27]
Design/dimensions/board.png

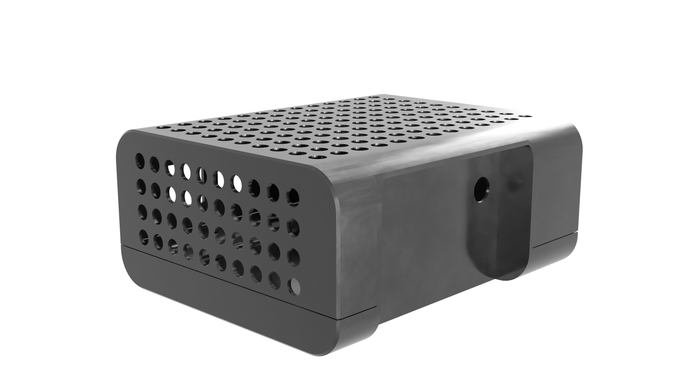
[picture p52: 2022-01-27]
Design/textures/case2.png

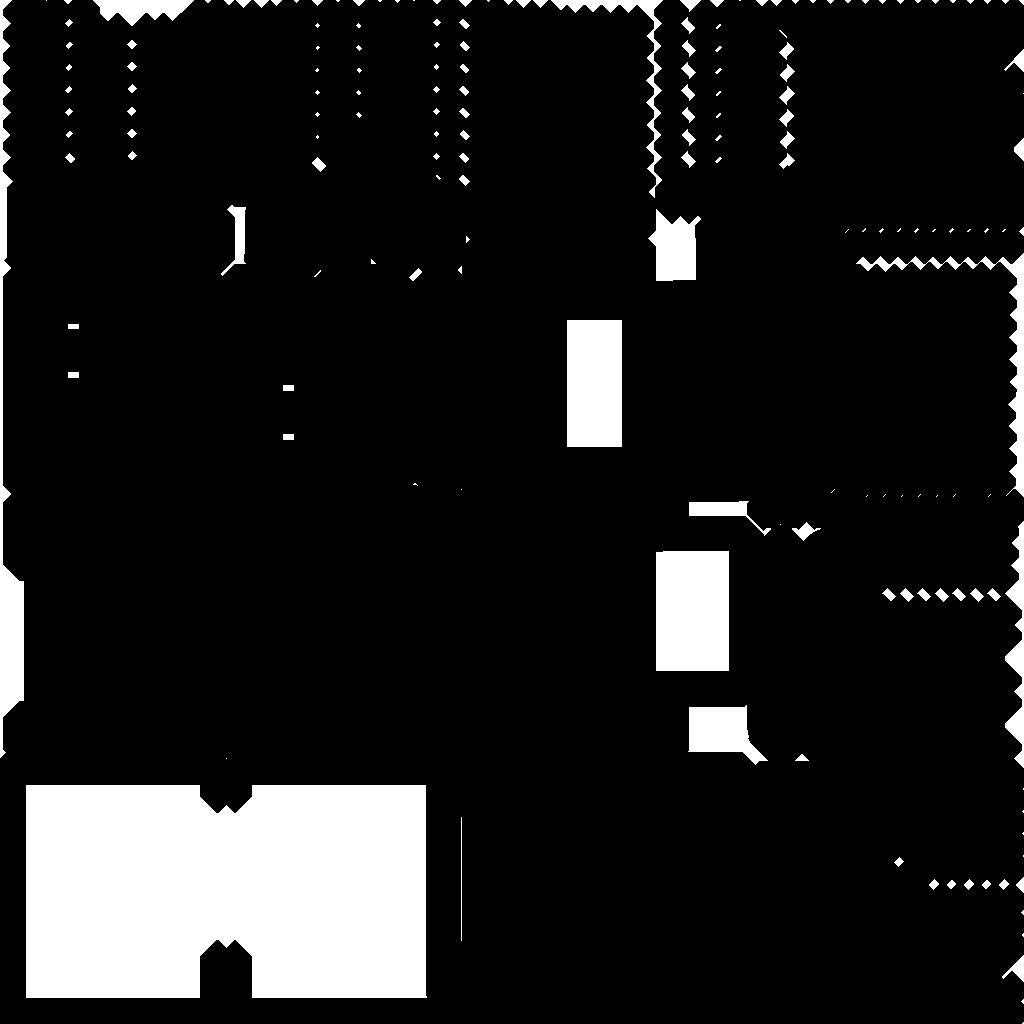
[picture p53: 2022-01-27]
Design/textures/base-color.png

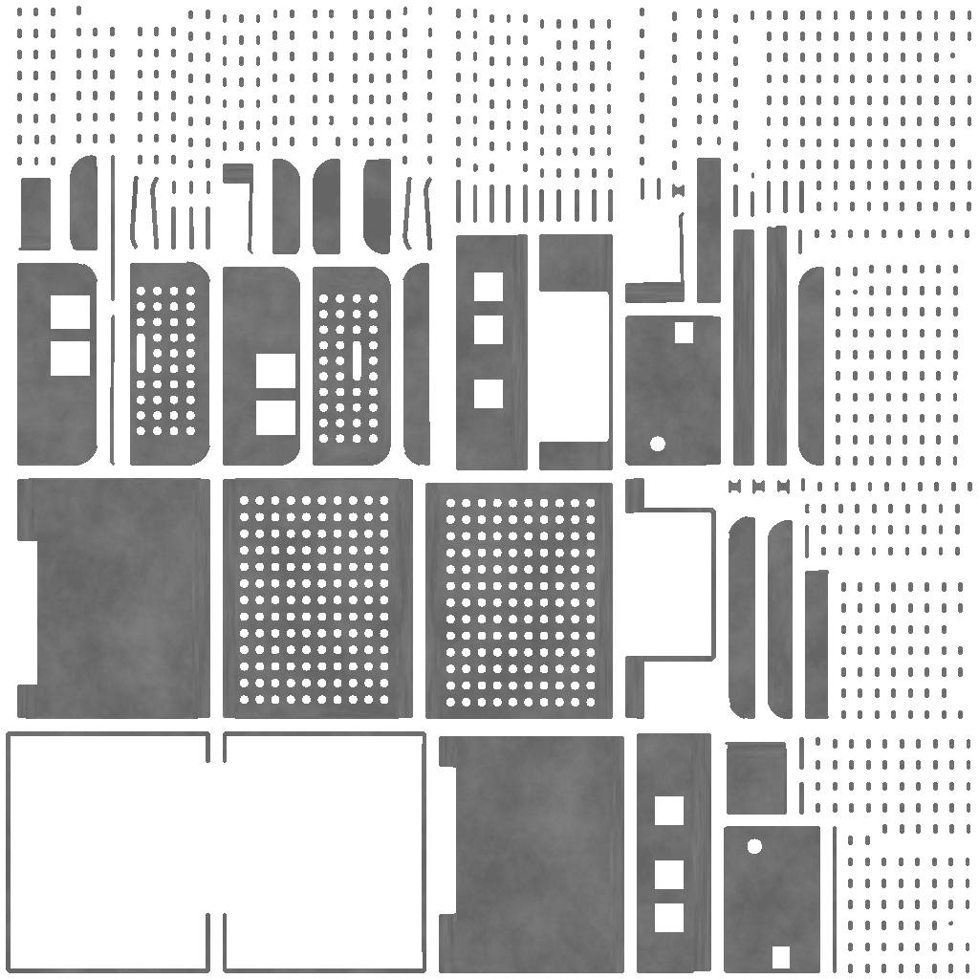
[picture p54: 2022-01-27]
Design/textures/roughness.png

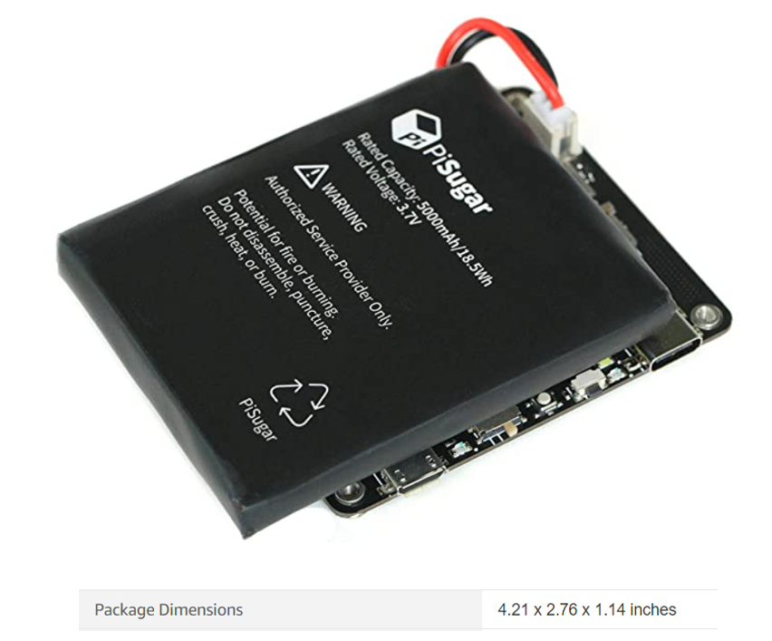
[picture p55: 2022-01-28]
Design/Dimensions/Battery.png

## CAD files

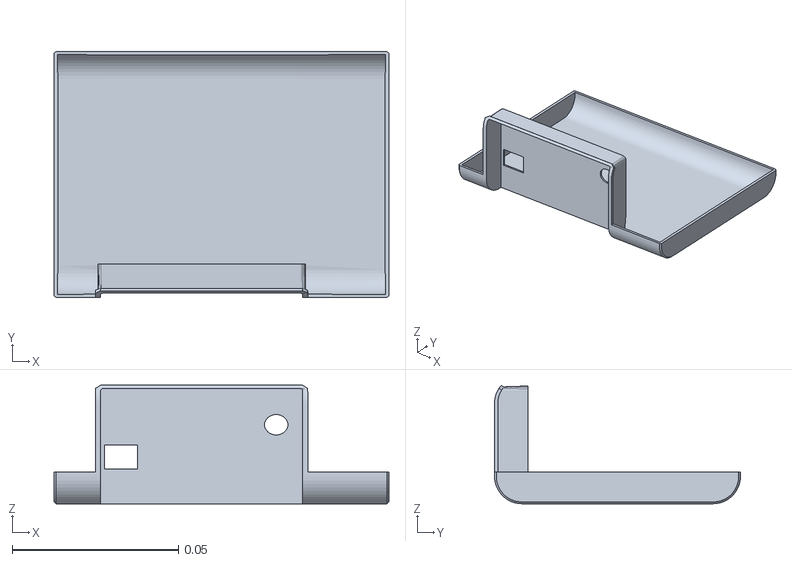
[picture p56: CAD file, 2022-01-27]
Design/Model/current_model/upper.stl
0.101 x 0.074 x 0.0356

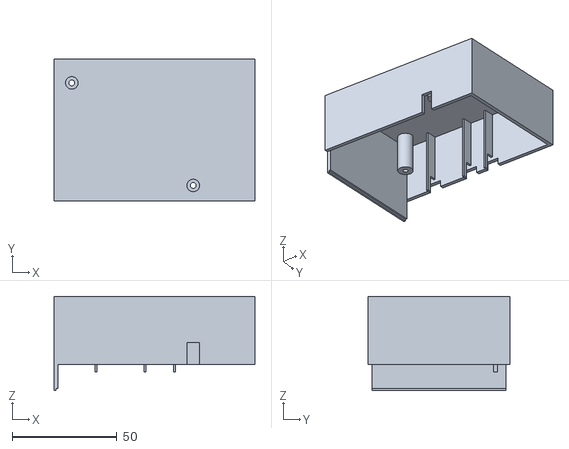
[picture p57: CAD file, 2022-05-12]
Design/Model/new_model_demo/V2-New-Eyes-Top.stl
96.0 x 68.0 x 45.0

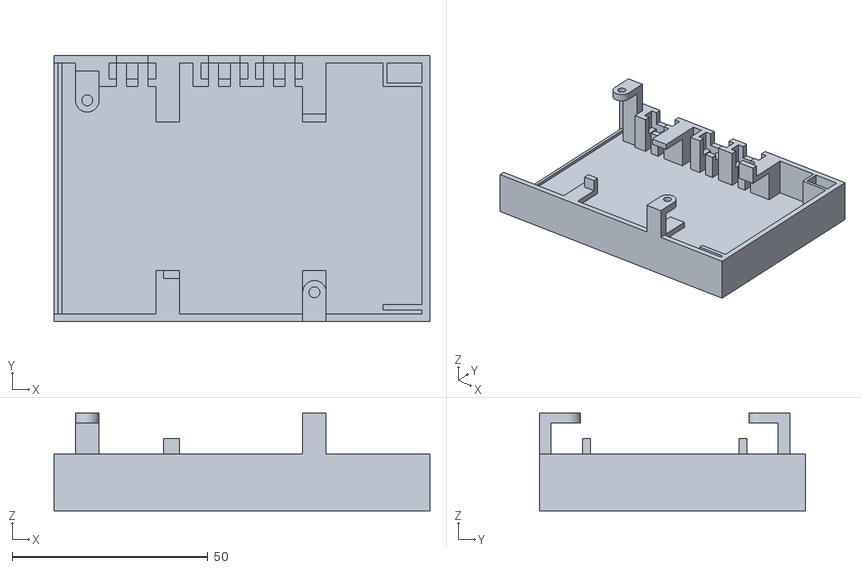
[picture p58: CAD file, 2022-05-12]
Design/Model/new_model_demo/V2-New-Eyes-Bottom.stl
96.0 x 68.0 x 25.0

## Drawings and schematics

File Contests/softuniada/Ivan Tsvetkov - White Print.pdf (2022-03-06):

# СЕРТИФИКАТ

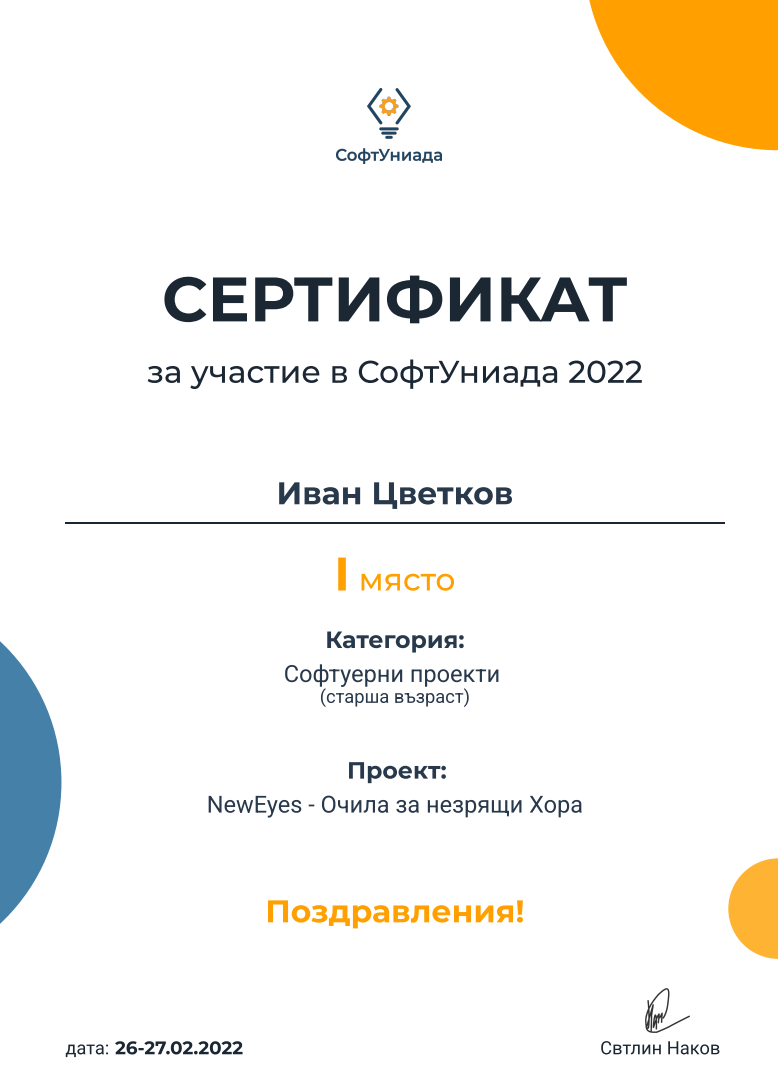
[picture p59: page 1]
Иван Цветков; I място; Поздравления!; дата: 26-27.02.2022; Свтлин Наков; Софтуерни проекти; (старша възраст); Проект:; Категория:

за участие в СофтУниада 2022

NewEyes - Очила за незрящи Хора

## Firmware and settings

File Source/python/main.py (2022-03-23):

#!/usr/bin/env python3
#from google.oauth2 import service_account
#from google.cloud import vision
from threading import Thread
from gpiozero import Button
import signal
#from pygame.locals import *
#from pygame import mixer
#from signal import pause
#import multiprocessing
#from gtts import gTTS
#import pygame.camera
import webbrowser
import pyautogui
#from speech_recog import *
import start_obj_recog
#import process_checker
import start_ocr
#import numpy as np
import subprocess
#import duo_google
from receipt_scanner import *
from predominant_clr import *
from book_ocr import *
#from crnn_ocr import *
from text_recognition import *
import argparse
#import _thread
import random
import time
import cv2
import sys
import io
import os


# Global variables
mode = 0


def synchronize_time():
    subprocess.call(['sh', "/home/pi/run_sync.sh"])
        

    ###################################
    # Executables and scripts
def call_google_api_ocr():
    start_ocr.call_google_api_ocr()
    # subprocess.call(["python3", "/home/pi/start_ocr.py"])
def call_obj_recog(path):
    start_obj_recog.call_object_recognition(path)
    # subprocess.call(["python3", "/home/pi/start_obj_recog.py"])
def realtime_detect_objects():
    realtime_yolo_obj_recog.realtime_yolo_object_recognition()
def voice_assistant():
    speech_process = subprocess.Popen(['python3', '/home/pi/speech_recog.py'])
    pid = speech_process.pid;
    
    with open('/home/pi/speech_process_pid.txt', 'w') as f:
        f.write(str(pid))
        
    print(pid)
    
    speech_process.wait()
    ###################################


def take_picture():
    def init_capture():
        subprocess.call(['sh', '/home/pi/guvc_force_capture.sh'])

    def stop_capture():
        time.sleep(3)
        subprocess.call(['sh', '/home/pi/stop_capture.sh'])

    def start_process():
        Thread(target=init_capture).start()
        Thread(target=stop_capture).start()

    def start_pressed():
        try:
            if os.path.exists("/home/pi/Desktop/output-1.jpg"):
                os.remove("/home/pi/Desktop/output-1.jpg")

            os.system("mpg321 first_beep.mp3 &")
            start_process()
            time.sleep(5.0)
            os.system('mpg321 second_beep.mp3 &')

        except Exception:
            pass
        finally:
            print("Picture taken successfully!")

    start_pressed()


def increase_mode_value():
    global mode
    
    
    mode += 1
    os.system("pkill mpg321")
    
    if mode == 1:
        os.system('mpg321 /home/pi/book_ocr_read.mp3 &')
        print("book reading mode")
        
    elif mode == 2:
        os.system('mpg321 /home/pi/street_ocr_read.mp3 &')
        print("street reading mode")
        
    elif mode == 3:
        os.system("mpg321 /home/pi/obj_recog.mp3 &")
        print("object recognition mode")
        
    elif mode == 4:
        os.system("mpg321 /home/pi/continuous_obj_recog.mp3 &")
        print("continuous object recognition mode")
        
    elif mode == 5:
        os.system('mpg321 /home/pi/duo.mp3 &')
        print("Remote duo assistant")
        
    elif mode == 6:
        # Terminate all chromium processes in order to avoid possible bottleneck
        #os.system("pkill chromium")
        
        os.system('mpg321 /home/pi/qr_barcode_recog.mp3 &')
        print("QR and barcode recognition")
        
    elif mode == 7:
        os.system('mpg321 /home/pi/rec_scanner.mp3 &')
        print("Receipt scanner")
        
    elif mode == 8:
        os.system('mpg321 /home/pi/money_detection.mp3 &')
        print("Detect money")
        
    elif mode == 9:
        os.system('mpg321 /home/pi/predominant_color.mp3 &')
        print("Predominant color detection")
    elif mode > 9:
        mode = 1
        os.system("mpg321 /home/pi/book_ocr_read.mp3 &")
        print("loop and back to the first mode")


def execute_action():
    #with open('speech_process_pid.txt') as f:
    #    pid = f.readline()
    #speech_pid = int(pid)RaspberryDummy0
    
    #os.kill(speech_pid, signal.SIGKILL)
    
    global mode
    os.system("pkill mpg321")
    
    if mode == 1:
        take_picture()
        time.sleep(3)
        
        # Call book ocr
        text_recognition()

        
        # call_google_api_ocr()
    
    elif mode == 2:
        take_picture()
        time.sleep(3)
        
        # Call street ocr
        street_ocr()
    
    elif mode == 3:
        take_picture()
        time.sleep(3)
        
        # Call object recognition
        path = '/home/pi/Desktop/output-1.jpg'
        call_obj_recog(path)

    elif mode == 4:
        os.system('mpg321 ready_signal.mp3 &')
        realtime = subprocess.Popen(['python3', '/home/pi/realtime_yolo_obj_recog.py'])
        pid = realtime.pid;
        
        with open('/home/pi/process_pid.txt', 'w') as f:
            f.write(str(pid))
            
        print(pid)
        
        realtime.wait()
        
    elif mode == 5:
        duo_process = subprocess.Popen(['python3', '/home/pi/duo_google.py'])
        pid = duo_process.pid;
        
        with open('/home/pi/process_pid.txt', 'w') as f:
            f.write(str(pid))
            
        print(pid)
        
        duo_process.wait()
        
        # Call duo assistant
        #duo_google.make_call()
        #os.system('python3 duo_google.py')
    elif mode == 6:
        # Call qr and barcode recognition
        os.system('mpg321 ready_signal.mp3 &')
        qr = subprocess.Popen(['python3', '/home/pi/qr_barcode.py'])
        pid = qr.pid
        
        with open('/home/pi/process_pid.txt', 'w') as f:
            f.write(str(pid))
            
        print(pid)
        
        qr.wait()
    elif mode == 7:
        
        take_picture()
        time.sleep(3)
        
        # Call receipt scanner
        scan_receipt()
    elif mode == 8:
        # Call money recognition 
        
        print("Money detection mode")
    elif mode == 9:
        
        take_picture()
        time.sleep(3)
        
        # Get predominant color 
        get_colour()
        
    #Thread(target=voice_assistant).start()
    
        
def duo_init():
    
    webbrowser.open('www.google.com')
    time.sleep(5)
    pyautogui.keyDown("ctrl")
    pyautogui.keyDown("shift")
    pyautogui.press("n")

    pyautogui.keyUp("ctrl")
    pyautogui.keyUp("shift")
    
    time.sleep(5)
    pyautogui.typewrite('https://duo.google.com/?web&utm_source=marketing_page_button_main')
    pyautogui.press("enter")
    time.sleep(20)  

    pyautogui.typewrite('rpidummy0@gmail.com')
    pyautogui.press("enter")
    time.sleep(6)
    
    pyautogui.typewrite('RaspberryDummy0')
    pyautogui.press("enter")

        
if __name__ == '__main__':
    # Time synchronization to ntp servers
    # Necessary for using the google vision api(s)

    #synchronize_time()
    #voice_assistant()

    # Indicate that the device is ready
    # Initialize the main case buttons

    os.system('mpg321 startup_signal.mp3 &')
    
    
    actionBtn = Button(4)
    nextBtn = Button(2)
    ###################################

    
    # Start the smart voice assistant worker thread
    
    
    Thread(target=duo_init).start()
    #Thread(target=voice_assistant).start()
    
    ###################################
    while True:

    # switch the mode to a different action
        actionBtn.when_pressed = execute_action
        nextBtn.when_pressed = increase_mode_value

    ###################################

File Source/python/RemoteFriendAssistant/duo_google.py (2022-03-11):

from pynput.keyboard import Key, Controller
from mysql.connector import Error
from google_speech import Speech
from threading import Thread
from gpiozero import Button
from subprocess import call
import RPi.GPIO as GPIO
import mysql.connector
import webbrowser
import pyautogui
import signal
import time
import sys
import os


Flag = 0
Stop = 0
digit = 0
letter = 0
call_flag = 0
call_counter = 0
contacts_counter = -1
names = []
numbers = []
number = ""
name = ""
selection_btn = Button(2)
append_btn = Button(3)
stop_btn = Button(4)


def stop():
    global Flag
    Flag = 4
    print(Flag)
    
def append():
    global digit
    global number
    
    os.system("pkill mpg321")
    if digit != -1:
        number += str(digit)
        print("Whole number: " + number)
    digit = -1
    
#def stop_while_loop():
#    GPIO.setwarnings(False) # Ignore warning for now
#    GPIO.setmode(GPIO.BOARD) # Use physical pin numbering
#    GPIO.setup(3, GPIO.IN, pull_up_down=GPIO.PUD_DOWN) # Set pin 3 to be an input pin and set initial value to be pulled low (off)
#    GPIO.add_event_detect(3, GPIO.RISING, callback=stop) # Setup event on pin 3 rising edge
#
#def append_digit_to_number():
#    GPIO.setwarnings(False) # Ignore warning for now
#    GPIO.setmode(GPIO.BOARD) # Use physical pin numbering
#    GPIO.setup(7, GPIO.IN, pull_up_down=GPIO.PUD_DOWN) # Set pin 3 to be an input pin and set initial value to be pulled low (off)
#    GPIO.add_event_detect(7, GPIO.RISING, callback=append) # Setup event on pin 3 rising edge


#def enter_digit(digit):
    
#call_counter = 0

def increase_digit():
    global digit
    digit += 1
    os.system("pkill mpg321")
    print(digit)
    
    if digit == 0:
        os.system("mpg321 /home/pi/duo_sound_files/zero.mp3 &")
    elif digit == 1:
        os.system("mpg321 /home/pi/duo_sound_files/one.mp3 &")
    elif digit == 2:
        os.system("mpg321 /home/pi/duo_sound_files/two.mp3 &")
    elif digit == 3:
        os.system("mpg321 /home/pi/duo_sound_files/three.mp3 &")
    elif digit == 4:
        os.system("mpg321 /home/pi/duo_sound_files/for.mp3 &")
    elif digit == 5:
        os.system("mpg321 /home/pi/duo_sound_files/five.mp3 &")
    elif digit == 6:
        os.system("mpg321 /home/pi/duo_sound_files/six.mp3 &")
    elif digit == 7:
        os.system("mpg321 /home/pi/duo_sound_files/seven.mp3 &")
    elif digit == 8:
        os.system("mpg321 /home/pi/duo_sound_files/eight.mp3 &")
    elif digit == 9:
        os.system("mpg321 /home/pi/duo_sound_files/nine.mp3 &")
    elif digit > 9:
        os.system("mpg321 /home/pi/duo_sound_files/zero.mp3 &")
        digit = 0


def increase_letter():
    global digit
    digit += 1
    
    os.system("pkill mpg321")
    if digit == 1:
        os.system("mpg321 /home/pi/duo_sound_files/letters/a.mp3 &")
    elif digit == 2:
        os.system("mpg321 /home/pi/duo_sound_files/letters/b.mp3 &")
    elif digit == 3:
        os.system("mpg321 /home/pi/duo_sound_files/letters/v.mp3 &")
    elif digit == 4:
        os.system("mpg321 /home/pi/duo_sound_files/letters/g.mp3 &")    
    elif digit == 5:
        os.system("mpg321 /home/pi/duo_sound_files/letters/d.mp3 &")
    elif digit == 6:
        os.system("mpg321 /home/pi/duo_sound_files/letters/e.mp3 &")
    elif digit == 7:
        os.system("mpg321 /home/pi/duo_sound_files/letters/j.mp3 &")
    elif digit == 8:
        os.system("mpg321 /home/pi/duo_sound_files/letters/z.mp3 &")
    elif digit == 9:
        os.system("mpg321 /home/pi/duo_sound_files/letters/i.mp3 &")
    elif digit == 10:
        os.system("mpg321 /home/pi/duo_sound_files/letters/i_short.mp3 &")
    elif digit == 11:
        os.system("mpg321 /home/pi/duo_sound_files/letters/k.mp3 &")
    elif digit == 12:
        os.system("mpg321 /home/pi/duo_sound_files/letters/l.mp3 &")
    elif digit == 13:
        os.system("mpg321 /home/pi/duo_sound_files/letters/m.mp3 &")
    elif digit == 14:
        os.system("mpg321 /home/pi/duo_sound_files/letters/n.mp3 &")
    elif digit == 15:
        os.system("mpg321 /home/pi/duo_sound_files/letters/o.mp3 &")
    elif digit == 16:
        os.system("mpg321 /home/pi/duo_sound_files/letters/p.mp3 &")
    elif digit == 17:
        os.system("mpg321 /home/pi/duo_sound_files/letters/r.mp3 &")
    elif digit == 18:
        os.system("mpg321 /home/pi/duo_sound_files/letters/s.mp3 &")
    elif digit == 19:
        os.system("mpg321 /home/pi/duo_sound_files/letters/t.mp3 &")
    elif digit == 20:
        os.system("mpg321 /home/pi/duo_sound_files/letters/u.mp3 &")
    elif digit == 21:
        os.system("mpg321 /home/pi/duo_sound_files/letters/f.mp3 &")
    elif digit == 22:
        os.system("mpg321 /home/pi/duo_sound_files/letters/h.mp3 &")
    elif digit == 23:
        os.system("mpg321 /home/pi/duo_sound_files/letters/c.mp3 &")
    elif digit == 24:
        os.system("mpg321 /home/pi/duo_sound_files/letters/chy.mp3 &")
    elif digit == 25:
        os.system("mpg321 /home/pi/duo_sound_files/letters/sh.mp3 &")
    elif digit == 26:
        os.system("mpg321 /home/pi/duo_sound_files/letters/sht.mp3 &")
    elif digit == 27:
        os.system("mpg321 /home/pi/duo_sound_files/letters/er_short.mp3 &")
    elif digit == 28:
        os.system("mpg321 /home/pi/duo_sound_files/letters/yu.mp3 &")
    elif digit == 29:
        os.system("mpg321 /home/pi/duo_sound_files/letters/q.mp3 &")
def append_name():
    global name
    global digit
    
    if digit == 1:
        name += "а"
    elif digit == 2:
        name += "б"
    elif digit == 3:
        name += "в"
    elif digit == 4:
        name += "г"
    elif digit == 5:
        name += "д"
    elif digit == 6:
        name += "е"
    elif digit == 7:
        name += "ж"
    elif digit == 8:
        name += "з"
    elif digit == 9:
        name += "и"
    elif digit == 10:
        name += "й"
    elif digit == 11:
        name += "к"
    elif digit == 12:
        name += "л"
    elif digit == 13:
        name += "м"
    elif digit == 14:
        name += "н"
    elif digit == 15:
        name += "о"
    elif digit == 16:
        name += "п"
    elif digit == 17:
        name += "р"
    elif digit == 18:
        name += "с"
    elif digit == 19:
        name += "т"
    elif digit == 20:
        name += "у"
    elif digit == 21:
        name += "ф"
    elif digit == 22:
        name += "х"
    elif digit == 23:
        name += "ц"
    elif digit == 24:
        name += "ч"
    elif digit == 25:
        name += "ш"
    elif digit == 26:
        name += "щ"
    elif digit == 27:
        name += "ь"
    elif digit == 28:
        name += "ю"
    elif digit == 29:
        name += "я"
        
    digit = 0
    print("Whole name: " + name)
        
def end_session():
    global Flag
    Flag = 3
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

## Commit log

2022-01-03 Автор
    .
2022-01-27 Reordering
    Reorder files, added 3D models, scripts, etc.
    [upper.stl]
2022-01-27 Upload Sample Datasets
2022-02-01 update case sprites
2022-02-02 added video samples
2022-05-12 Ready for NOIT
    [V2-New-Eyes-Bottom.stl, V2-New-Eyes-Top.stl, upper.stl]
